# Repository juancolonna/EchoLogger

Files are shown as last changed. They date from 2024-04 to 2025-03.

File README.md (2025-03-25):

# EchoLogger Development Project

This repository contains the development project for EchoLogger, initiated and managed by the Institute of Computing (Instituto de Computação - IComp) at the Federal University of Amazonas (UFAM).

- **Project Leader and Coordinator:** Prof. PhD. Juan G. Colonna - [juancolonna@icomp.ufam.edu.br](mailto:juancolonna@icomp.ufam.edu.br)
- **Hardware Developer:** PhD. Márcio Alencar - [macalencar@gmail.com](mailto:macalencar@gmail.com)

## Contents

- **Hardware:** EasyEDA Project File and its variants as backups.
- **Software:** Micropython Firmware, basic libraries, and example codes.
- **Board Images:** Footprints, 2D/3D Images, and Logos.
- **Schematics:** Circuit schematics.
- **Documents:** General project documents, datasheets, and specifications.

## Project Overview

EchoLogger is a modularized low-cost development board project primarily aimed at monitoring environmental variables and recording sound. Its modular design facilitates the custom assembly of components to meet specific customer requirements. The device is tailored to streamline the non-industrialized production process by allowing the soldering of prefabricated components.

## Hardware Specifications

| TOP VIEW | BOTTOM VIEW|
|---|---|
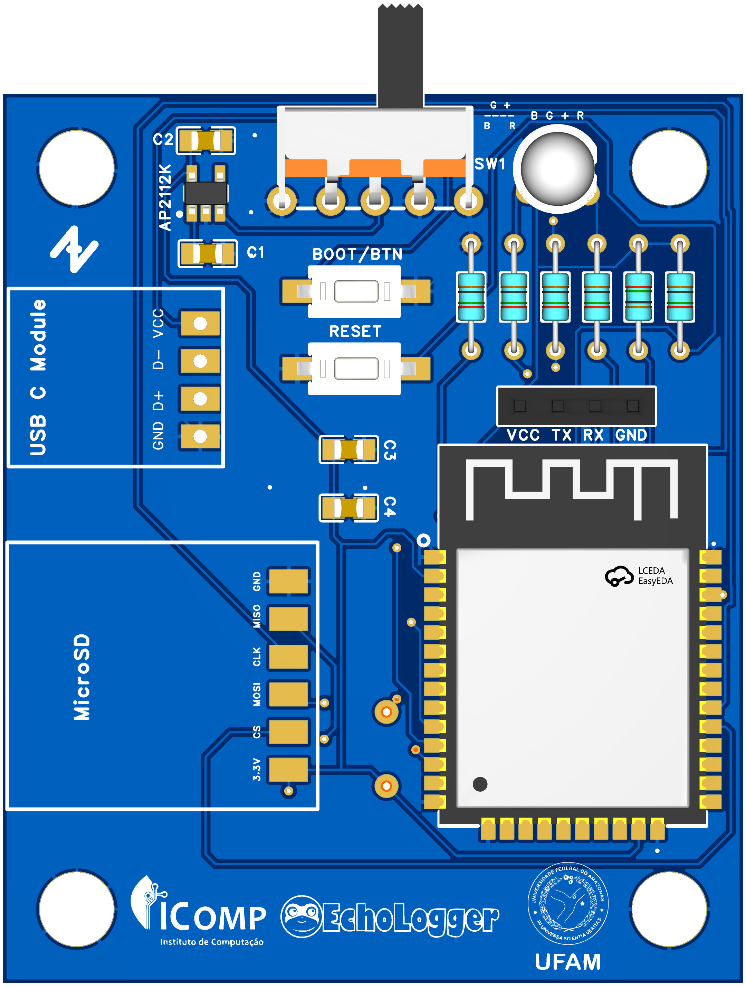
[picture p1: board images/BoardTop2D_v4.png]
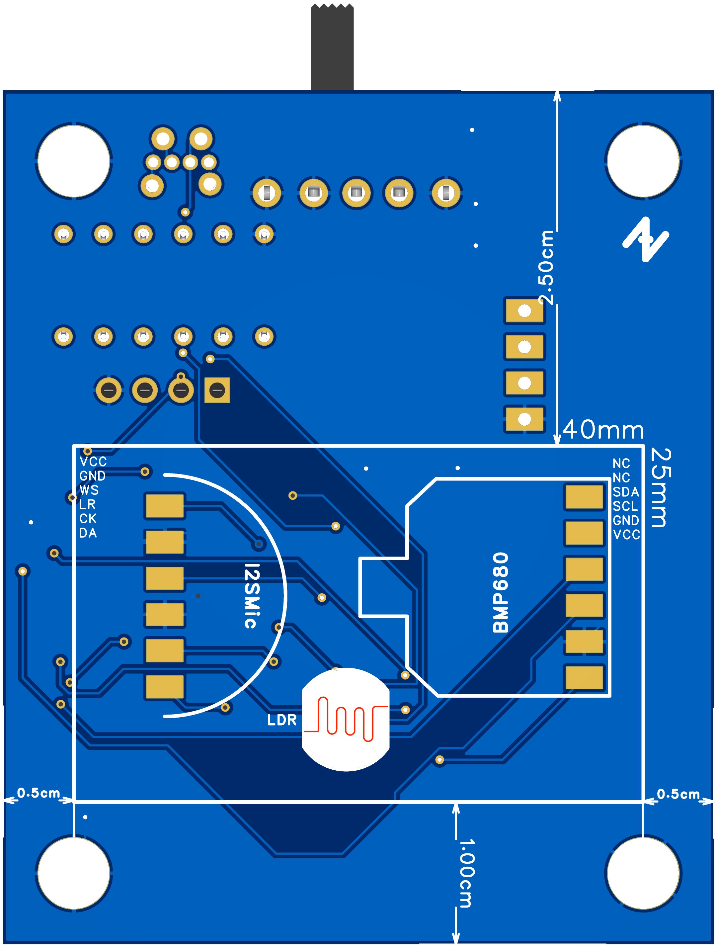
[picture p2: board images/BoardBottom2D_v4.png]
|||

- **Dimensions:** 600mm (length) x 500mm (width) x 130mm (height)
- **Microcontroller:** ESP32-WROOM-32S (BLE 4.0 & WiFi 802.11 b/g)
- **Sensors:**
  - I2C 4x1 Sensor BME680 (Temperature, Humidity, Air Pressure & Air Quality)
  - I2S Mic for noise recording
  - SPI MicroSD Card Module
  - LDR Sensor
- **Connectivity:** USB-C Module
- **Power Regulation:** Voltage Regulator AP2112K-3.3V
- **User Interface:** Reset Button, Boot Firmware Loader Button, RGB Led (Common Cathode), On/Off Switch
- **Additional Features:** UART Exposed Pins, 4x 5mm Holes, Isolated sensors on the bottom face for safety exposure

## Power Specifications

### Supply
- **AP2112K-3.3V:** 2.8V~6.5V @ 800mA (Regulated to 3.3v @ 600mA)

### Operation mode
- **Reading Sensors:** 50mA
- **Micro SD Writing:** 70mA
- **Deepsleep:** 15mA
- **Waking Up:** 100mA
- **Bluetooth:** 170mA (RX) ~ 200mA (TX)
- **WiFi:** 170mA (RX) ~ 260mA (TX)

### Consumption Estimation
- **Routine:** 1 min recording, 5 min sleeping
- **Cycle:** Sleep -> Wake Up -> Record -> Save Data -> Back to Sleep
- **Power Consumption Estimation:** 30mAh (3.3V - 0.15Wh)

### Deployment example!
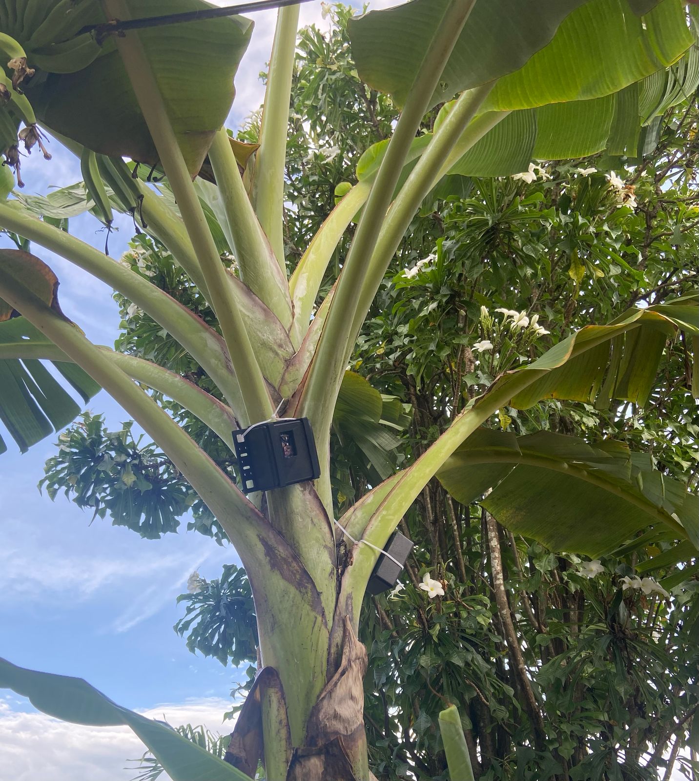
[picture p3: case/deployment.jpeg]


<!-- ## Additional Information -->

---
Feel free to reach out for any inquiries or collaborations!

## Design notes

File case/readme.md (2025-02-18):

STL files for case 3D printing

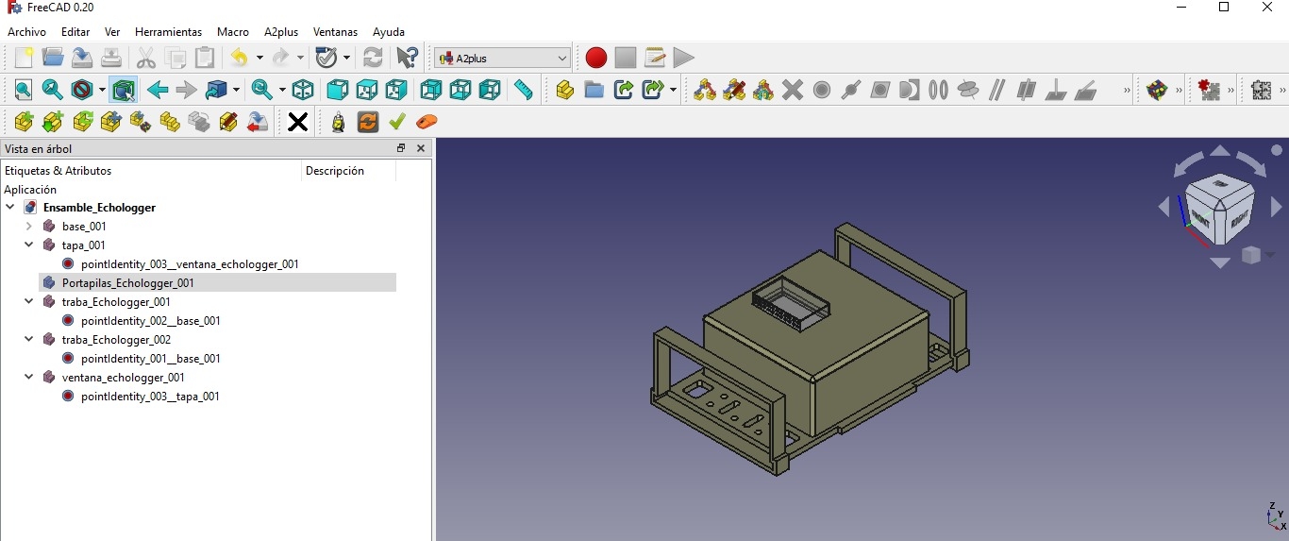
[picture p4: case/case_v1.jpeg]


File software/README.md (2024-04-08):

# Software Examples

This is folder contain the basic firmware and some python codes available for testing the board.

For that you may install the [esptool.py](https://github.com/espressif/esptool) for burning the firmware in the ESP, use the [mpy-cross](https://gitlab.com/alelec/mpy_cross) to 'compile' the `.py` codes and save some space, and then, send the `*.mpy` compiled files to the board using the [adafruit-ampy](https://github.com/scientifichackers/ampy) tool and a serial module.

Note: This tutorial used `Python 3.10.6`

### Install the requirements tools
```
pip install esptool
pip install adafruit-ampy
pip install mpy-cross
```

### Flashing the Micropython Firmware

1. Connect the power supply (5v) to the USB-C connector.
2. Connect the [Serial Module](https://www.smartkits.com.br/conversor-ftdi-ft232rl-com-chave-3-3v5v-vermelho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) (at 3.3v only) to the UART pins on the board (No need to connect VCC).
3. Identify the serial port of your serial module (Example using Windows - COM6).
4. Holding the `Boot/BTN` down, press & relase the `Reset` button.
5. Run the following command.

```
python -m esptool --chip esp32 --port COM6 erase_flash
```

After that, reset your device, execute the steps `4` and `5` again and run:

```
python -m esptool --chip esp32 --port COM6 --baud 460800 write_flash -z 0x1000 ./Micropython/ESP32_GENERIC-20231005-v1.21.0.bin
```

Reset the board again and it's done! Now your device has the Micropython firmware installed. 

We recommend to use the latest [Micropython for ESP32-WROOM](https://micropython.org/download/ESP32_GENERIC/) Version.

### Uploading the Demo Codes

This section describes how to send the basic library, available in `EX00_BasicLibs`, and use them in a demo application, available in `EX01_Bluetooth`. This demo tests all reseouces available in the board (mic, sensor, led, sdcard and bluetooth).

By using the [adafruit-ampy](https://github.com/scientifichackers/ampy) tool, you must save the basic library into the controller, for that, run the following commands:

```
ampy -b 115200 -p COM6 put ./EX00_BasicLibs/ble_advertising.py ble_advertising.py 
ampy -b 115200 -p COM6 put ./EX00_BasicLibs/bme680.py bme680.py 
ampy -b 115200 -p COM6 put ./EX00_BasicLibs/i2smic.py i2smic.py 
ampy -b 115200 -p COM6 put ./EX00_BasicLibs/RGBLib.py RGBLib.py 
```

Finally, save the main code `main.py` to run the device as a BLE Advertiser. For that you may install the `EchoLogger.apk` (Recommended) app in the `EX00_Extras` or use the `NRFConnect` from [PlayStore](https://play.google.com/store/apps/details?id=no.nordicsemi.android.mcp&pcampaignid=web_share) or [AppleStore](https://apps.apple.com/br/app/nrf-connect-for-mobile/id1054362403?platform=iphone).

```
ampy -b 115200 -p COM6 put ./EX01_Bluetooth/boot.py main.py 
```

Now, reset the device, run the app in yout smartphone, and connect to device called `EchoLogger`(NRFConnect) or click `Find and Connect` (EchoLogger.apk`)

Done!

### Connecting to the board using UART

Open you terminal monitor (suggested: [VSCode Serial Monitor by Microsoft](https://github.com/microsoft/vscode-serial-monitor_)) and connect to the board using the following configuration:

- Monitor Mode: Serial
- View Mode: Text
- Port: COM6 (*just following the previous example)
- Baud Rata: 115200
- Line ending: CRLF
- Data Bits: 8
- Stop bits: 1
- Parity: None
- DTR:  Checked
- RST: Checked

If everything went well, your device is ready to run your python commands.

This communication allows to interact with the Micropython terminal and run commands on demand, for example: 

```
print("Hello World")
```

Visit the [Micropython Documentation](https://docs.micropython.org/en/latest/) page for further informations on how to interacts with Micropython.

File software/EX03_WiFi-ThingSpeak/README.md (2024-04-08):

# Wifi + Thingspeak

This folder contains an example how to send data from your device to the [Thingspeak](https://thingspeak.com/) over wifi.

### Lib mrequests

This code uses a library called [mrequests)[https://github.com/SpotlightKid/mrequests] that implements the main REST methods (`GET, POST, PUT, UPDATE & DELETE`). To use it, run:

```
ampy -b 115200 -p COM6 put ./EX03_WIfi-Thingspeak/mrequests.py mrequests.py
```

Befor upload the `main.py` we need to update the `_APIKEY` value. This key must be generated in the section `API Keys > Write API Key` from [Thingspeak](https://thingspeak.com) dashboard. Make sure your Channel Settings contains 5 Fields at this order `Temperature, Humidity, Air Pressure, Air Quality` and `Light Intensity`:

```
#Thingspeak
_APIKEY = "YOUR_API_KEY_HERE"
_URL='https://api.thingspeak.com/update?api_key={}&field1={}&field2={}&field3={}&field4={}&field5={}'
```

You might have to include your Wifi's name (`_SSID``) and its password (`_PWD``)

```
#Wifi Credentials
_SSID="YOUR_SSID_HERE"
_PWD ="WIFI_PASSWORD_HERE"
```

Save the file and upload it to the board

```
ampy -b 115200 -p COM6 put ./EX03_WIfi-Thingspeak/main.py main.py
```

After that, reboot your device and access your [Thingspeak](https://thingspeak.com). 

Note: The API ignores demands an interval of 30s  between the last and a new request.

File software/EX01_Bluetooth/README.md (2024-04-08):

# BLE Demo

This folder contains the main code for a basic application using [Bluetooth Low Energy](https://docs.micropython.org/en/latest/library/bluetooth.html)

### BLE Service

This demos advertised the services as `Environmental Sensing Service` (`0x181A`) as defined [BLESpecifications](https://github.com/macalencar/PC20230001/tree/main/05_Docs/BLESpecifications)

This devices propagates the following characteristics :

- **Serial RX:** 6E400002-B5A3-F393-E0A9-E50E24DCCA9E   (Receive Data)
- **Serial TX:** 6E400002-B5A3-F393-E0A9-E50E24DCCA9E   (Transmit Data)
- **Air Pressure:** 0x2A6D
- **Temperature:** 0x2A6E
- **Humidity:** 0x2A6F
- **Air Quality:** 0x2AF9
- **Illuminance:** 0x2AFB
- **Device Time:** 0x2B90
- **Storege Free Space**: 0x2B04

This demo propagates the device name as `EchoLogger` and all values are published as a `Float 16`.

For further information go to [Bluetooth.org](https://www.bluetooth.com/bluetooth-resources/intro-to-bluetooth-low-energy/) or check the [Micropython BLE Documentation](https://docs.micropython.org/en/latest/library/bluetooth.html)

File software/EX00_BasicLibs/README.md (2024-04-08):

# Basic Libraries

This folder contains the basic libraries that help you to test the board funcionalities.

### RGBLib

Library that controlls the RGB led which is physically attached to the following ESP32 pins as follows:

- VCC: 3.3v
- RED: IO04
- GREEN: IO26
- BLUE: IO27

By using the `RGBLib` is is possible to instatiate an object that controlls the led as follow:

```
import RBGLib
LED = RBGLib.Controller(4,26,27)
LED.boot()

```

This library contains a set of pre-configured colors: `["black","red","green","blue","yellow","orange","pink","purple","cyan","white"]`. You may change the color by calling the method `LED.set('<COLOR>')`:

```
LED.set('blue')
LED.set('white')
LED.set('black')
LED.set('green')
```

You may also set manualy a led collor by define the RGB values using the method `LED.man(r,g,b)`. Each `r,g,b` values may assume any value from `0` to `1023`:

```
LED.man(100,200,300)
```

### BME680

This library controls the sensor [BME650](https://datasheet.lcsc.com/lcsc/1811141211_Bosch-Sensortec-BME680_C125972.pdf) by using a [SoftI2C](https://docs.micropython.org/en/latest/library/machine.I2C.html) classe which is connected to the board as the following:

- VCC: 3.3v
- GND: GND
- SDA: IO22
- SCL: IO21

You may create an object to controll the BME680 module by indicating a [SoftI2C](https://docs.micropython.org/en/latest/library/machine.I2C.html) object as following:

```
from machine import SoftI2C, Pin
import bme680

i2c = SoftI2C(scl=Pin(22), sda=Pin(21))
bme = BME680_I2C(i2c=i2c)

print("Temperature: {} ºC\n".format(bme.temperature))
print("Humidity: {} %".format(bme.humidity))
print("Air Pressure: {} HPa".format(bme.pressure))
print("Air Quality: {} IAQ".format(bme.gas))

```

### I2S Mic

This module controlls the [I2S](https://docs.micropython.org/en/latest/library/machine.I2S.html#machine.I2S) Microphone, it requires a [MicrSD Card](https://docs.micropython.org/en/latest/library/machine.SDCard.html) to store the recorded audio.

The SDCard module is connected to `ESP32`` as follows:

- VCC: 3.3v
- GND: GND
- CS: IO05
- MOSI: IO23
- CLK: IO18
- MISO: IO19

The I2SMic is connectes as follows:

- GND: GND
- VCC: 3.3v
- WS: IO25
- L/R: GND (it could be VCC)
- CK: IO32
- DA: IO33

Make sure that your sd card if formated as `FAT32` and inserted in the module's slot. After that, execute the following commands:

```
from machine import SDCard
import i2smic
import time

i2c = SDCard(slot=2)
os.mount(_SD, "/sd") 
MIC = i2smic.Controller()

MIC.record('/sd/output_file.wav')
time.sleep(10)
MIC.stop()

```

The `*.WAV` file are stored in the micro SD card.

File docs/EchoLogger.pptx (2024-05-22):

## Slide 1

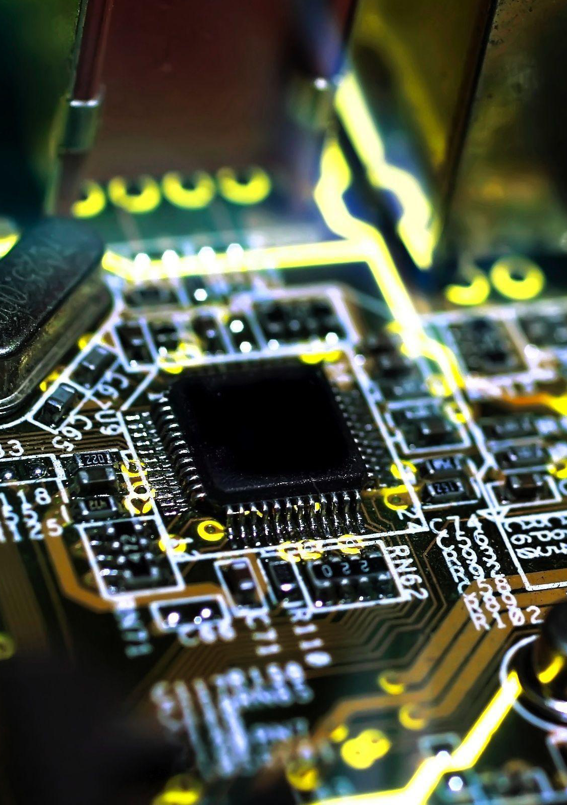
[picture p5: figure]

Reuniões Semanais #6
PC2023:0001:V3

ATA

Alencar Tecnologia da Amazonia.
CNPJ: 45.845.459/0001-24

## Agenda

- Hardware Overview;
- Components Description;
- Power Consumption;
- Data Sampling;
- Application;

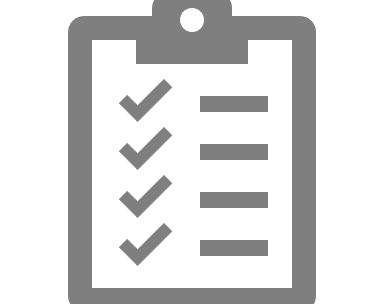
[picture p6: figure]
Área de Transferência Marcada com preenchimento sólido

Alencar Tecnologia da Amazonia
CNPJ: 45.845.459/0001-24

ATA

## Hardware Overview

- Custom Board
- Controller:
  - ESP32 WROOM (BLE v4.0 & Wifi 802.11 b/g)
  - Embedded RTC
  - Firmware Micropython 1.20
- Storage:
  - micro SD Card Slot
- Sensors:
  - 4x1 I2C Temperature, Humidity, Air Pressure and Air Quality
  - Mic I2S
  - LDR 5mm (ADC)

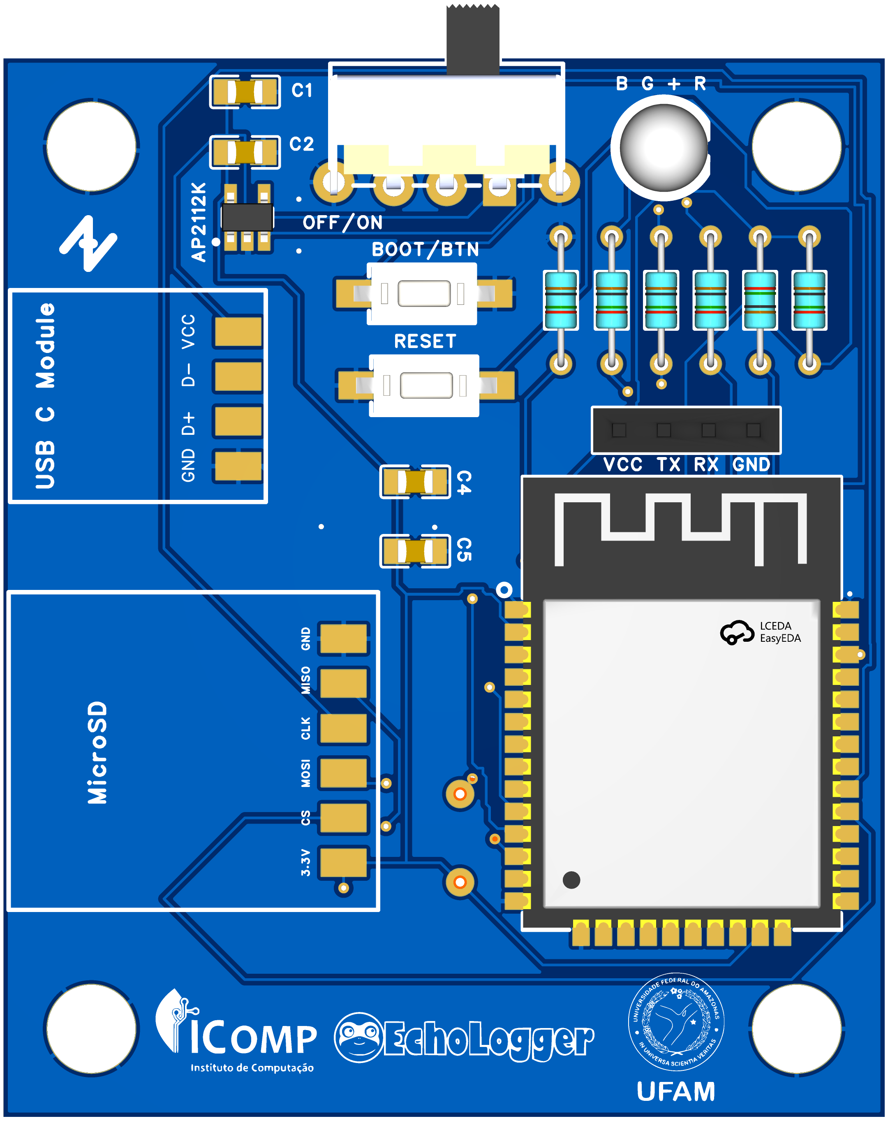
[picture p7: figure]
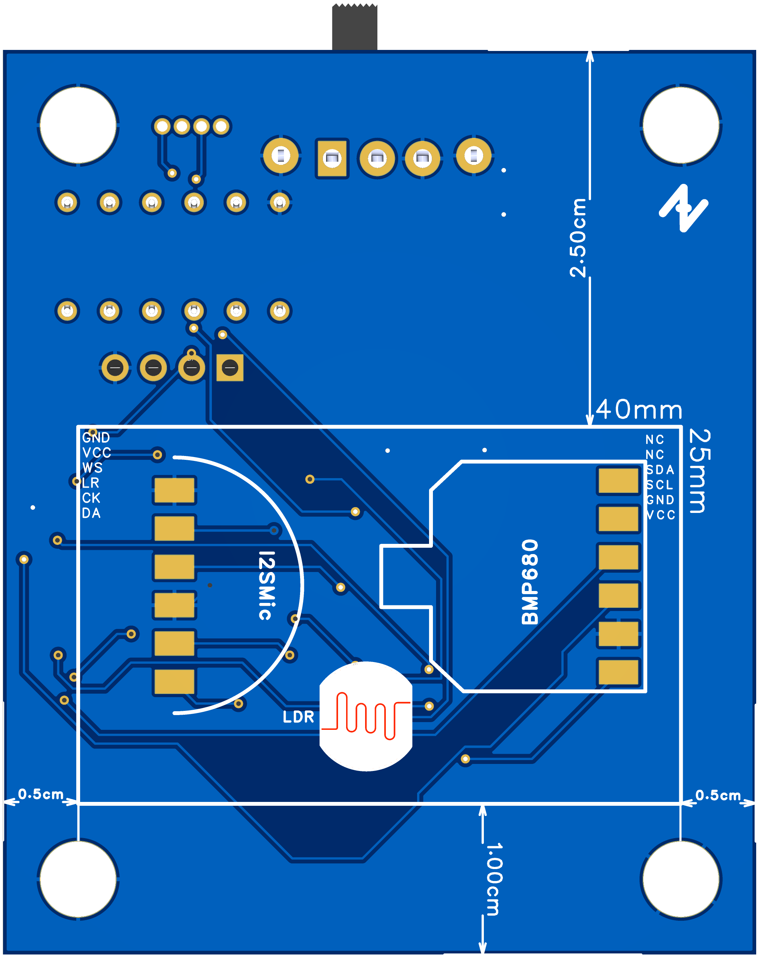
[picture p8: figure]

Alencar Tecnologia da Amazonia
CNPJ: 45.845.459/0001-24

ATA

## Hardware Overview

- Custom Board
- Dimensions:
  - 60mm x 50mm x 20mm
- Other characteristics:
  - 4x Holes for board supporting: 5mm
  - 1x Led RGB THP
  - 2x Pushbuttons: Reset / Boot (firmware writing or regular button)
  - USB Breakout Pads
  - Voltage Regulator AP2112K-TGR-3.3v
  - Exposed UART vias

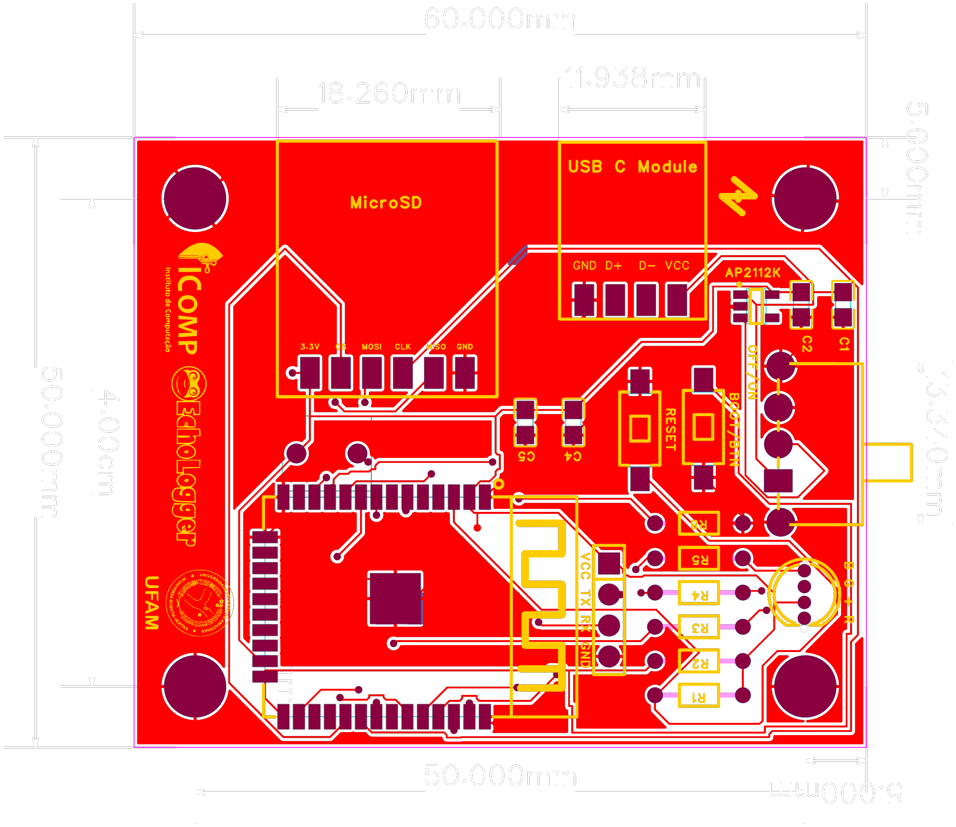
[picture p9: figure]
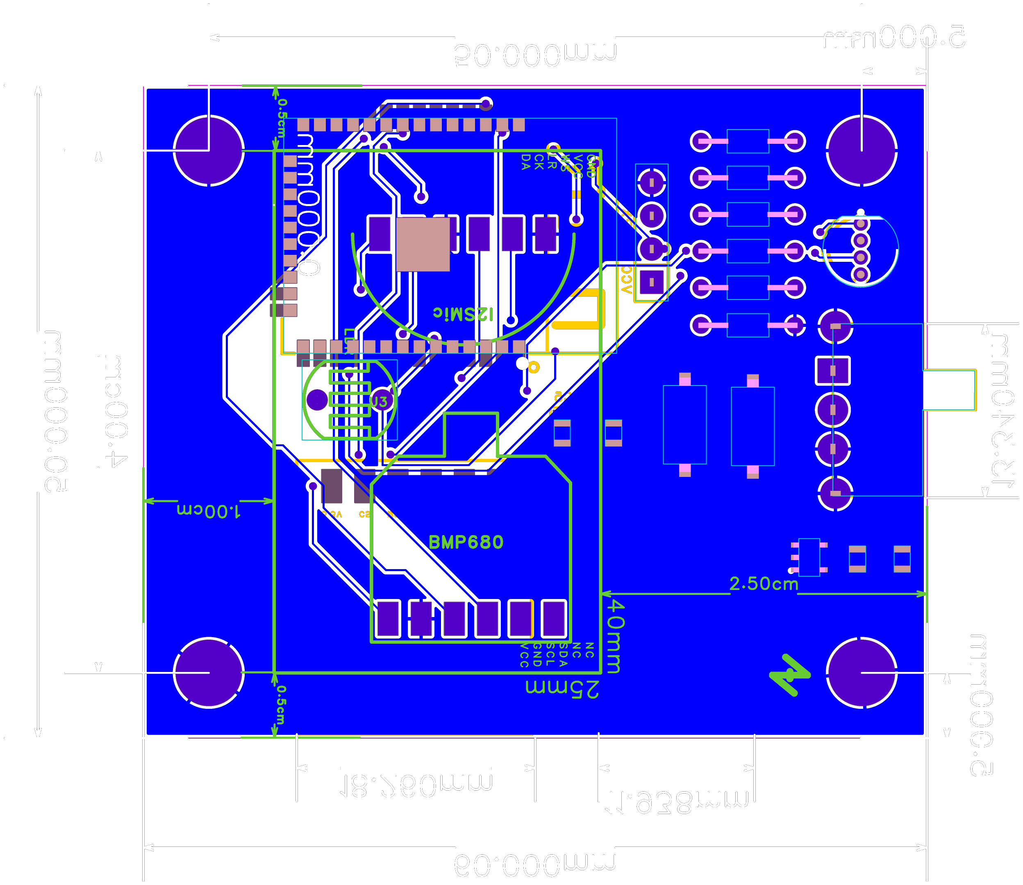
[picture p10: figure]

Alencar Tecnologia da Amazonia
CNPJ: 45.845.459/0001-24

ATA

## Components Descriptions

Component | Value
USB Power Supply (Module) | ~ 0.40
Voltage Regulator (AP2112) | ~ 0.10
LDR (Photoresistor) 5mm | ~ 0.01
Led RGB THP 5mm | ~ 0.02
MicroSD Module | ~ 0.25
I2S Mic | ~ 1.80
BME680 4x1 Sensor | ~ 3.70
ESP32-WROOM-32 | ~ 3.50
PCB | ~ 5.00
PowerBank (50A) | ~ 20.00
Waterproof Box – IP67 – 20x12x7.5cm | ~ 10.00
ESTIMATED COST | ~ 44,78

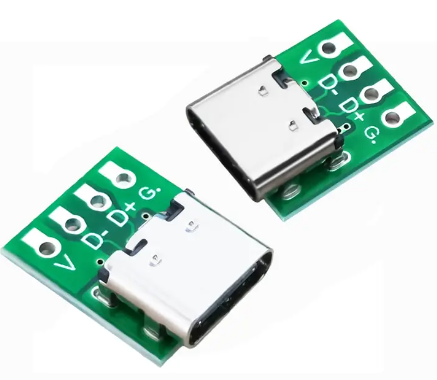
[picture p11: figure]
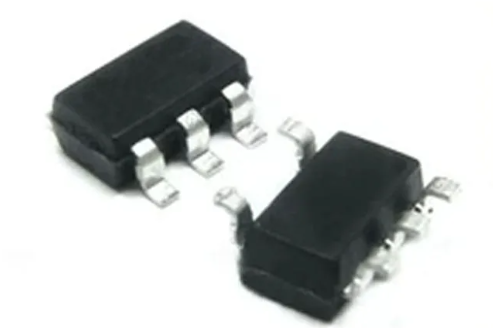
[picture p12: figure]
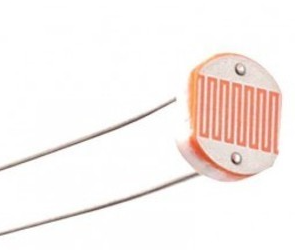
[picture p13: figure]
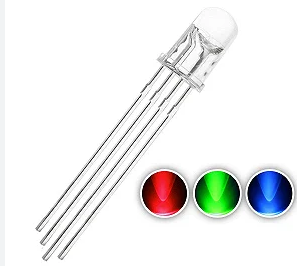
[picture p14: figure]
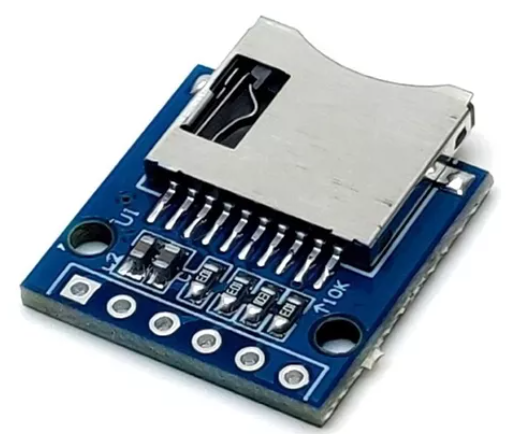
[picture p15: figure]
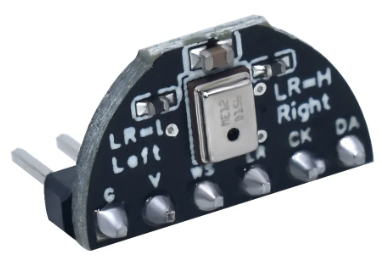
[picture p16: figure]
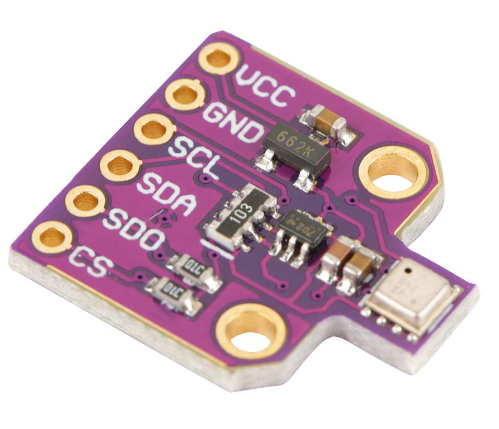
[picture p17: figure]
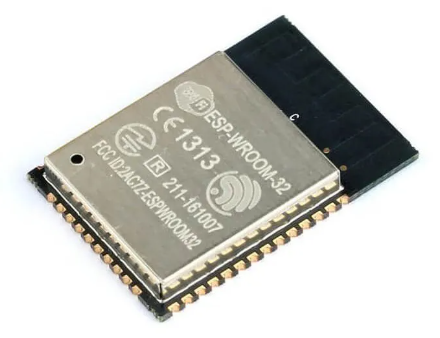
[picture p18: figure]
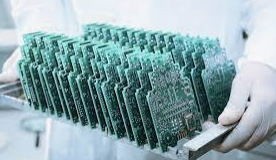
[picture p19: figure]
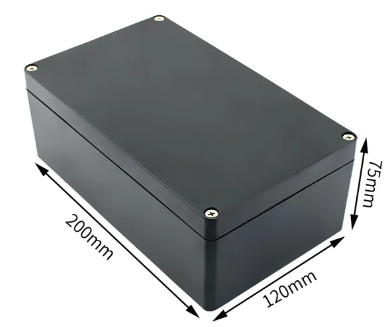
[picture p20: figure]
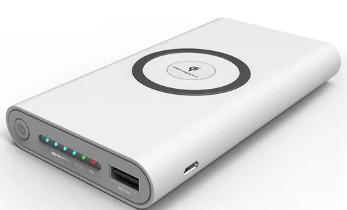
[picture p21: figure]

Alencar Tecnologia da Amazonia
CNPJ: 45.845.459/0001-24

ATA

## Power Consumption

- Power Supply:
- APK2112: 2.8V ~ 6.5V @ 800A - 3.3V @ 600mA
- Operation mode:
- Reading Sensors: 50mA
- SD Writing: 70mA
- Deepsleep: 15mA
- Waking up: 100mA
- BLE: 170mA (TX) ~ 200mA (RX)

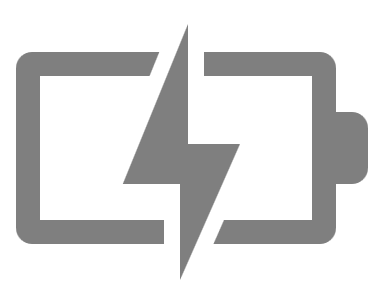
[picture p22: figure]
Carregamento da bateria com preenchimento sólido

Alencar Tecnologia da Amazonia
CNPJ: 45.845.459/0001-24

ATA

## Power Consumption

- Consumption Estimation:
- Routine: 1 min recording, 5 min sleeping;
- Cycle: Sleep (5min), Wakeup (2s), Record (1min), Writing (2s)
- Repetat the cycle for 1 hour (~ 10 cycles / hour)

Current (mA/h) | Activity (duration/hour)
12,5 | Sleeping (~50 min/hour)
0,555556 | Waking Up (~20sec/hour)
8,333333 | Recording (~10min/hour)
0,388889 | Writing (~20sec/hour)
21,77778 | Routine Consumption (mAh)
Estimation 30mAh (3.3V - 0.15 Wh)

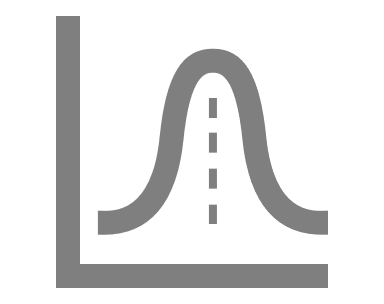
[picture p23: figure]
Distribuição normal com preenchimento sólido

Alencar Tecnologia da Amazonia
CNPJ: 45.845.459/0001-24

ATA

## Data sampling

Alencar Tecnologia da Amazonia
CNPJ: 45.845.459/0001-24

ATA

## Data sampling

- Audio Samples:
- File name: record_N.wav
- Format: WAV
- Storage Consumption: 2.55MB/min
- Audio splited in 1 min chunks

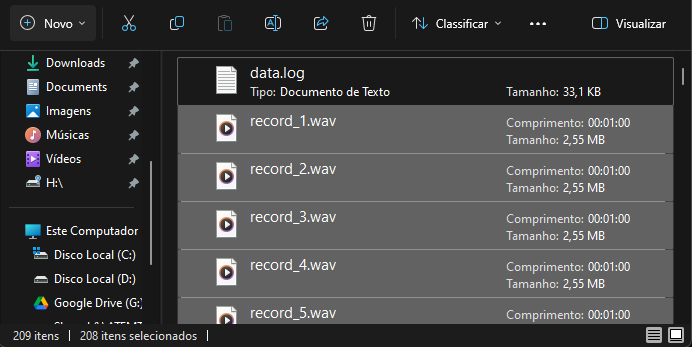
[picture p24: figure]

Alencar Tecnologia da Amazonia
CNPJ: 45.845.459/0001-24

ATA

## Application

- Bluetooth Low Energy Configuration
  - Real time data (Sensor Readings)
  - Date Time / GPS Coordinates Sync
  - Scheduling Management
- Activity Scheduling
  - Days of Week
  - Start Time
  - Start Date
  - Recording Interval: 0 (disabled) ~ 24h
  - Multiple Scheduling

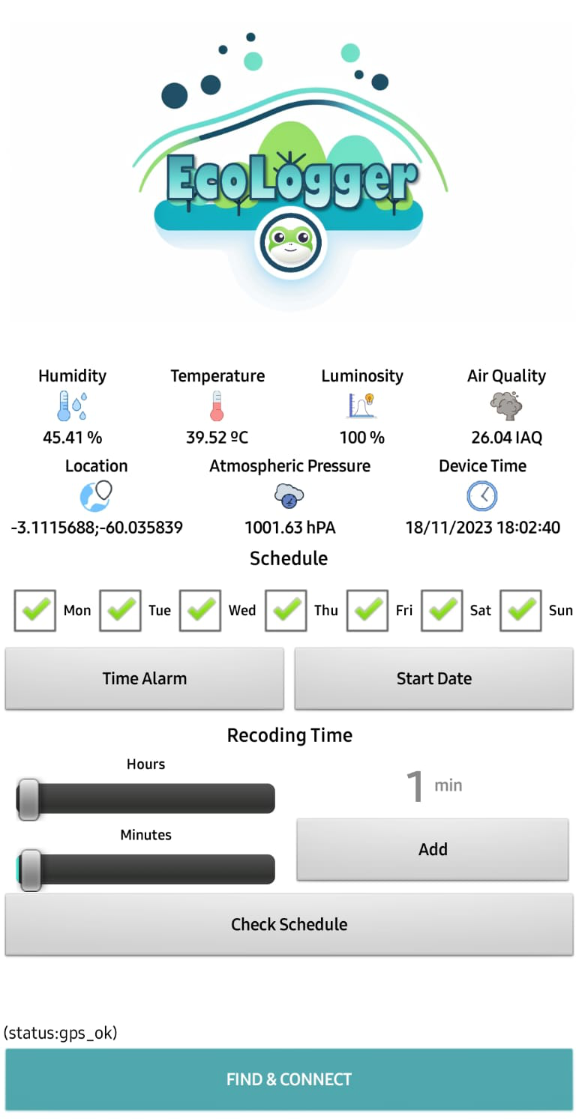
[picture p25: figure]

Alencar Tecnologia da Amazonia
CNPJ: 45.845.459/0001-24

ATA

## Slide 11

Obrigado!
PC2023:0001:V3

ATA

Alencar Tecnologia da Amazonia.
CNPJ: 45.845.459/0001-24

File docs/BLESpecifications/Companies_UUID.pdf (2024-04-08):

Embedded Planet | Agora BLE Reference Specification | BLE GATT Profile Specification
Date: 17-July-2019 | Document Version: 0.4 | Prepared by: G. Beckstein

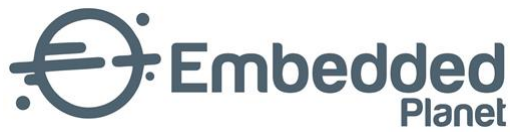
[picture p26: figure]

Embedded Planet Confidential – Do not copy or reproduce without expressed written consent of Embedded Planet, Inc.

### Document Revision History

Date | Description | Author | Version
18-June-2019 | Initial version. | G. Beckstein | 0.1
24-June-2019 | Revised from internal comments | G. Beckstein | 0.2
1-July-2019 | Modified services/characteristics to more closely mirror LWM2M | G. Beckstein | 0.3
17-July-2019 | Changed ICM20602 and LSM9DS1 data struct members from int16 to float | G. Beckstein | 0.4
23-October-2019 | Changed temperature Celsius (0x2A1F) to temperature (0x2A6E) | G. Beckstein | 0.5
23-October-2019 | Added Firmware Revision String characteristic (0x2A26) to Device Information Service (0x180A) | G. Beckstein | 0.5

### Sign-Off

Signature | Date
Marketing | ☐
Operations | ☐
Purchasing | ☐
Engineering | ☐

### Distribution

CEO | ☐
Admin | ☐
Engineering | ☐
Marketing | ☐
Operations | ☐
Purchasing | ☐

Embedded Planet, Inc.
4760 Richmond Road, Suite 400 Warrensville Heights, OH 44128 216-245-4180 p
216-292-0561 f

### 1.0 Purpose

This BLE Protocol Specification (BPS) document describes the Bluetooth Low Energy (BLE) profile of the Agora Product. This specification is based on standards published by the Bluetooth SIG and the array of sensors built into the Agora hardware.

For detailed hardware functionality, please refer to the Hardware Functional Specification (DES0263).

### 2.0 Document Conventions

General definition of requirement terms:
- SHALL - This word means that the definition is an absolute requirement of the specification.
- SHALL NOT - This phrase means that the definition is an absolute prohibition of the specification.
- SHOULD- This word means that there may exist valid reasons in particular circumstances to ignore a particular item, but the full implications must be understood and carefully weighed before choosing a different course.
- SHOULD NOT - This phrase means that there may exist valid reasons in particular circumstances when the particular behavior is acceptable or even useful, but the full implications should be understood, and the case carefully weighed before implementing any behavior described with this label.
- MAY - This word mean that an item is truly discretionary.

### 3.0 References

Description | Document | Rev / Date | Owner

### 4.0 Acronyms and Abbreviations

Term | Description
EPI | Embedded Planet Inc.
BSP | Board Support Package
SIG | Bluetooth Special Interest Group
BLE | Bluetooth Low Energy (aka Bluetooth Smart)
GAP | Generic Access Profile (part of BLE specification)
GATT | Generic Attribute Profile (part of BLE specification)
UUID | Universally Unique Identification Number
IAQ | Indoor Air Quality
IMU | Inertial Measurement Unit
ALS | Ambient Light Sensor

### 5.0 Definitions

Term | Description
BLE Characteristic | A BLE endpoint encapsulating a single data point. Characteristics typically expose up to 20 bytes at a time of data in a single transaction.
BLE Service | A service defines a set of mandatory and optional characteristics that exist under one UUID.
BLE Profile | A profile defines a set of mandatory and optional services that exist on a device.
BLE Peripheral | A connectable device that periodically broadcasts advertisements of its presence with a small payload describing itself. A BLE central can connect to this device.
BLE Central | A device that scans for advertising peripherals and issues connection packets. (e.g.: a BLE-enabled smartphone)

### 6.0 Description of Pairing Procedure

### 6.1 Advertising – No Paired Centrals

When first powered on, the Agora device shall advertise as a BLE peripheral. It shall advertise in undirected connectable mode. In this mode, the peripheral allows persistent connections from central devices and periodically broadcasts general advertisements to all nearby central devices.
The advertisement payload shall contain identifiable information that will distinguish the Agora BLE peripheral from other nearby BLE peripherals. This identifiable information shall consist of at least:
1.) The 128-bit Agora BLE Service UUID as described in section 7. This may be used by the central device application to filter unrelated BLE peripherals.
2.) The last two bytes of the device’s Bluetooth MAC address which may be used to uniquely identify a single Agora device when several are advertising within range.

### 6.2 Connection Procedure and Pairing

When a connection is initiated by a central device, for example a compatible application on a nearby gateway, the Agora device shall request the connection security to be upgraded. As the central, the gateway application is responsible for carrying out this request and may choose to initiate the BLE bonding procedure.
During the BLE bonding procedure, encryption keys are securely exchanged between the central and peripheral. Both the central and peripheral store the keys and unique identifiers in non-volatile memory.

### 6.3 Advertising – Paired Centrals

When an Agora device powers on and has a previously paired central stored in memory, it shall advertise as a BLE peripheral in directed connectable mode. In this mode, advertisements shall be targeted towards the last central the Agora device was connected to. This enables a connection to be established more quickly with a previously paired central.
If the intended central fails to reconnect within several seconds, the Agora device shall then revert to advertise in undirected connectable mode as described in section 6.1.

### 7.0 Agora BLE Profile Description

Custom BLE service UUIDs from a single manufacturer typically derive from the same 128-bit base UUID. The Embedded Planet base UUID is shown in the table below:

Base UUID

0000xxxx-8dd4-4087-a16a-04a7c8e01734
The ‘x’ characters indicate the position of the alias of BLE properties (service and characteristic UUIDs).

Services and characteristics standardized by the Bluetooth SIG cover common BLE application requirements. Standardized services and characteristics are typically identified by a shorter, 16-bit UUID. This 16-bit UUID can be expanded using the Bluetooth SIG’s 128-bit base UUID. However, for brevity, this document will only refer to the short-form, 16-bit UUID of standard services and characteristics.

The Agora product encompasses several product variants with optional components left unpopulated in some cases. As a result, some services described below may not be present in the profile of a specific Agora unit. If a service is not present it means that part is not populated on the board. The connected application should be aware of this and respond to missing services appropriately.

### 7.1 Services

The Agora BLE profile shall consist of several standardized and custom services. Bluetooth SIG standardized services included in the profile are listed in the table below:

Standard Services

UUID | Name | Relevant Specification
0x1800 | Generic Access Service | org.bluetooth.service.generic_access (https://www.bluetooth.com/wp-content/uploads/Sitecore-Media-Library/Gatt/Xml/Services/org.bluetooth.service.generic_access.xml)
0x180A | Device Information Service | org.bluetooth.service.device_information (https://www.bluetooth.com/wp-content/uploads/Sitecore-Media-Library/Gatt/Xml/Services/org.bluetooth.service.device_information.xml)

Each on-board sensor or actuator is associated with a corresponding custom service. Custom services are described in the table below:

Custom Services

Alias | Name | Full UUID
0x0001 | BME680 Service | 00000001-8dd4-4087-a16a-04a7c8e01734
0x0002 | Si7021 Service | 00000002-8dd4-4087-a16a-04a7c8e01734
0x0003 | ICM-20602 6-Axis IMU Service | 00000003-8dd4-4087-a16a-04a7c8e01734
0x0004 | LSM9DS1 9-Axis IMU Service | 00000004-8dd4-4087-a16a-04a7c8e01734
0x0005 | MAX44009 Ambient Light Service | 00000005-8dd4-4087-a16a-04a7c8e01734
0x0006 | VL53L0X Time-of-Flight Service | 00000006-8dd4-4087-a16a-04a7c8e01734
0x0008 | LED Service | 00000008-8dd4-4087-a16a-04a7c8e01734
0x0009 | Battery Voltage Service | 00000009-8dd4-4087-a16a-04a7c8e01734

The characteristics of each of these services are described in the following sections.

Non-standardized characteristics will be associated with a specified data format as outlined by the Bluetooth SIG here. (https://www.bluetooth.com/specifications/assigned-numbers/format-types/)
The units of the data will also be described. This information shall be available “on-air” by accessing the specific
characteristic’s Characteristic Presentation Format descriptor. (https://www.bluetooth.com/wp-content/uploads/Sitecore-Media-Library/Gatt/Xml/Descriptors/org.bluetooth.descriptor.gatt.characteristic_presentation_format.xml)

### 7.1.1 Generic Access Service

The Generic Access service contains generic information about the device. All available Characteristics are read only. The table below summarizes implemented characteristics of this service:

Standard Characteristics

UUID | Name | Permissions | Relevant Specification
0x2A00 | Device Name | Read | org.bluetooth.characteristic.gap.device_name (https://www.bluetooth.com/wp-content/uploads/Sitecore-Media-Library/Gatt/Xml/Characteristics/org.bluetooth.characteristic.gap.device_name.xml)
0x2A01 | Appearance | Read | org.bluetooth.characteristic.gap.appearance (https://www.bluetooth.com/wp-content/uploads/Sitecore-Media-Library/Gatt/Xml/Characteristics/org.bluetooth.characteristic.gap.appearance.xml)

### 7.1.2 Device Information Service

The Device Information Service exposes manufacturer and/or vendor information about a device. The table below summarizes implemented characteristics of this service:

Standard Characteristics

UUID | Name | Permissions | Relevant Specification
0x2A29 | Manufacturer Name | Read | org.bluetooh.characteristic.manufacturer_name_string (https://www.bluetooth.com/wp-content/uploads/Sitecore-Media-Library/Gatt/Xml/Characteristics/org.bluetooth.characteristic.manufacturer_name_string.xml)
0x2A24 | Model Number String | Read | org.bluetooth.characteristic.model_number_string (https://www.bluetooth.com/wp-content/uploads/Sitecore-Media-Library/Gatt/Xml/Characteristics/org.bluetooth.characteristic.model_number_string.xml)
0x2A25 | Serial Number String | Read | org.bluetooth.characteristic.serial_number_string (https://www.bluetooth.com/wp-content/uploads/Sitecore-Media-Library/Gatt/Xml/Characteristics/org.bluetooth.characteristic.serial_number_string.xml)
0x2A26 | Firmware Revision String | Read | org.bluetooth.characteristic.firmware_revision_string (https://www.bluetooth.com/wp-content/uploads/Sitecore-Media-Library/Gatt/Xml/Characteristics/org.bluetooth.characteristic.firmware_revision_string.xml)
0x2A27 | Hardware Revision String | Read | org.bluetooth.characteristic.hardware_revision_string (https://www.bluetooth.com/wp-content/uploads/Sitecore-Media-Library/Gatt/Xml/Characteristics/org.bluetooth.characteristic.hardware_revision_string.xml)
0x2A28 | Software Revision String | Read | org.bluetooth.characteristic.software_revision_string (https://www.bluetooth.com/wp-content/uploads/Sitecore-Media-Library/Gatt/Xml/Characteristics/org.bluetooth.characteristic.software_revision_string.xml)

### 7.1.3 BME680 Service

The BME680 is a highly integrated environmental sensor capable of transducing ambient temperature, pressure, relative humidity, and relative VOC concentration. By combining these readings, the application can give a measure of indoor air quality (IAQ). The BME680 service characteristics are listed in the table below:

Standard Characteristics

UUID | Name | Permissions | Relevant Specification
0x2A6E | Temperature | Read, Notify, Indicate | org.bluetooth.characteristic.temperature (https://www.bluetooth.com/wp-content/uploads/Sitecore-Media-Library/Gatt/Xml/Characteristics/org.bluetooth.characteristic.temperature.xml)
0x2A6F | Humidity | Read, Notify, Indicate | org.bluetooth.c haracteristic.humidity (https://www.bluetooth.com/wp-content/uploads/Sitecore-Media-Library/Gatt/Xml/Characteristics/org.bluetooth.characteristic.humidity.xml)
0x2A6D | Pressure | Read, Notify, Indicate | org.bluetooth.characteristic.pressure (https://www.bluetooth.com/wp-content/uploads/Sitecore-Media-Library/Gatt/Xml/Characteristics/org.bluetooth.characteristic.pressure.xml)

Custom Characteristics

Alias | Name | Units (ID) | Data format (ID) | Permissions | Full UUID

0x1001 | Estimated CO2 Concentration | Concentration in ppm (0x27C4) | float32 (0x14) | Read, Notify, Indicate | 00001001-8dd4-4087-a16a-04a7c8e01734
0x2001 | Estimated b-VOC Equivalents | Concentration in ppm (0x27C4) | float32 (0x14) | Read, Notify, Indicate | 00002001-8dd4-4087-a16a-04a7c8e01734
0x3001 | Indoor Air Quality Score (0-500) | Unitless (0x2700) | uint16 (0x06) | Read, Notify, Indicate | 00003001-8dd4-4087-a16a-04a7c8e01734
0x4001 | Indoor Air Quality Accuracy Score (0-3) | Unitless (0x2700) | uint8 (0x04) | Read, Notify, Indicate | 00004001-8dd4-4087-a16a-04a7c8e01734
0x5001 | Gas Resistance | Ohm (0x272A) | uint32 (0x08) | Read, Notify, Indicate | 00005001-8dd4-4087-a16a-04a7c8e01734

The Indoor Air Quality Score corresponds to the descriptions in the following table:

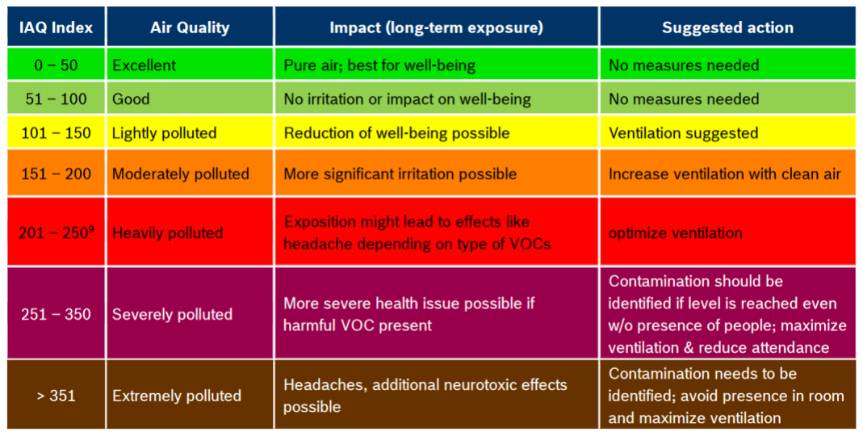
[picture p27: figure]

### 7.1.4 Si7021 Service

The Si7021 combines a relative humidity and temperature sensor. It offers a redundant temperature and humidity reading when populated with the BME680 (described in section 7.1.1), or a simpler solution for temperature and humidity sensing if used alone. The Si7021 service exposes a subset of the characteristics included in the BME680 service.

Standard Characteristics

UUID | Name | Permissions | Relevant Specification
0x2A6E | Temperature | Read, Notify, Indicate | org.bluetooth.characteristic.temperature (https://www.bluetooth.com/wp-content/uploads/Sitecore-Media-Library/Gatt/Xml/Characteristics/org.bluetooth.characteristic.temperature.xml)
0x2A6F | Humidity | Read, Notify, Indicate | org.bluetooth.characteristic.humidity (https://www.bluetooth.com/wp-content/uploads/Sitecore-Media-Library/Gatt/Xml/Characteristics/org.bluetooth.characteristic.humidity.xml)

### 7.1.5 ICM-20602 6-Axis IMU Service

The ICM-20602 is a 6-axis inertial measurement unit providing 3-axis accelerometer and 3-axis gyroscope readings.

Custom Characteristics

Alias | Name | Units (ID) | Data format (ID) | Permissions | Full UUID
0x1003 | Accelerometer XYZ | Acceleration (0x2713) | struct (0x1B) (see 7.1.5.1) | Read | 00001003-8dd4-4087-a16a-04a7c8e01734
0x2003 | Gyroscope XYZ | Angular Veloctity (0x2743) | struct (0x1B) | Read | 00002003-8dd4-4087-a16a-04a7c8e01734

### 7.1.5.1 Accelerometer/Gyroscope XYZ Structure

The accelerometer and gyroscope XYZ characteristics shall contain a struct that encapsulates three 32-bit floating-point values for each axis, X, Y, and Z, respectively. They shall be packed into a 12-byte packet.

### 7.1.6 LSM9DS1 9-Axis IMU Service

The LSM9DS1 is a 9-axis IMU and offers an additional/alternate source of accelerometer and gyroscope data as well as 3-axis magnetometer data. As such, the LSM9DS1 service contains the same characteristics as the ICM-20602 Service (described in section 7.1.3) and additional characteristics related to the magnetometer functionality.

Custom Characteristics

Alias | Name | Units (ID) | Data format (ID) | Permissions | Full UUID
0x1003 | Accelerometer XYZ | Acceleration (0x2713) | struct (0x1B) (see 7.1.5.1) | Read | 00001003-8dd4-4087-a16a-04a7c8e01734
0x2003 | Gyroscope XYZ | Angular Velocity (radians/sec) (0x2743) | struct (0x1B) | Read | 00002003-8dd4-4087-a16a-04a7c8e01734
0x3004 | Magnetometer XYZ | Magnetic Flux Density (teslas) (0x272D) | struct (0x1B) | Read | 00003004-8dd4-4087-a16a-04a7c8e01734

### 7.1.7 MAX44009 Ambient Light Sensor Service

The MAX44009 incorporates two ambient light sensors – each having a different response to various wavelengths of light. One of the sensors rejects infrared light to better represent the ambient light conditions as seen by the human eye. The other sensor accepts more infrared and less visible light. The two readings are combined to provide a more “realistic” reading under a variety of lighting conditions.

The MAX44009 ALS Service has the following characteristics:
Custom Characteristics
Alias | Name | Units (ID) | Data format (ID) | Permissions | Full UUID
0x1005 | Ambient Light | Lux (0x2731) | float32 (0x14) | Read, Notify, Indicate | 00001005-8dd4-4087-a16a-04a7c8e01734

### 7.1.8 VL53L0X Time-of-Flight Service

The VL53L0X time-of-flight sensor can measure the distance to nearby objects up to 2 meters away. An example application of this data is the possibility of tamper detection if the device is moved or opened by an unauthorized person.

The VL53L0X Time-of-Flight Service has the following characteristics:

Custom Characteristics

Alias | Name | Units (ID) | Data format (ID) | Permissions | Full UUID
0x1006 | Distance | Meter (0x2701) (in increments of 0.001) | uint16 (0x06) | Read, Notify, Indicate | 00001006-8dd4-4087-a16a-04a7c8e01734

### 7.1.9 LED Service

The LED service exposes read/write control to the state of the on-board LED. This service functions identically to the service implemented in the Mbed-OS BLE LED example application found here. (https://github.com/ARMmbed/mbed-os-example-ble/tree/master/BLE_LED) A value of true is associated with the illuminated LED state.

Custom Characteristics

Alias | Name | Units (ID) | Data format (ID) | Permissions | Full UUID
0x1008 | LED State | Unitless (0x2700) | boolean (0x01) | Read, Write | 00001008-8dd4-4087-a16a-04a7c8e01734

### 7.1.10 Battery Voltage Service

The Battery Voltage Service exposes a raw reading of the current on-board battery voltage. This can be used to estimate remaining battery life.

Custom Characteristics

Alias | Name | Units (ID) | Data format (ID) | Permissions | Full UUID
0x1009 | Battery Voltage | Volts (0x2728) | float32 (0x14) | Read, Notify, Indicate | 00001009-8dd4-4087-a16a-04a7c8e01734

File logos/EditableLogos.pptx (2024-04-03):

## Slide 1

EchoLogger


EchoLogger

00EchoLogger

EchoLogger

00EchoLogger

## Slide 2


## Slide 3


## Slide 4


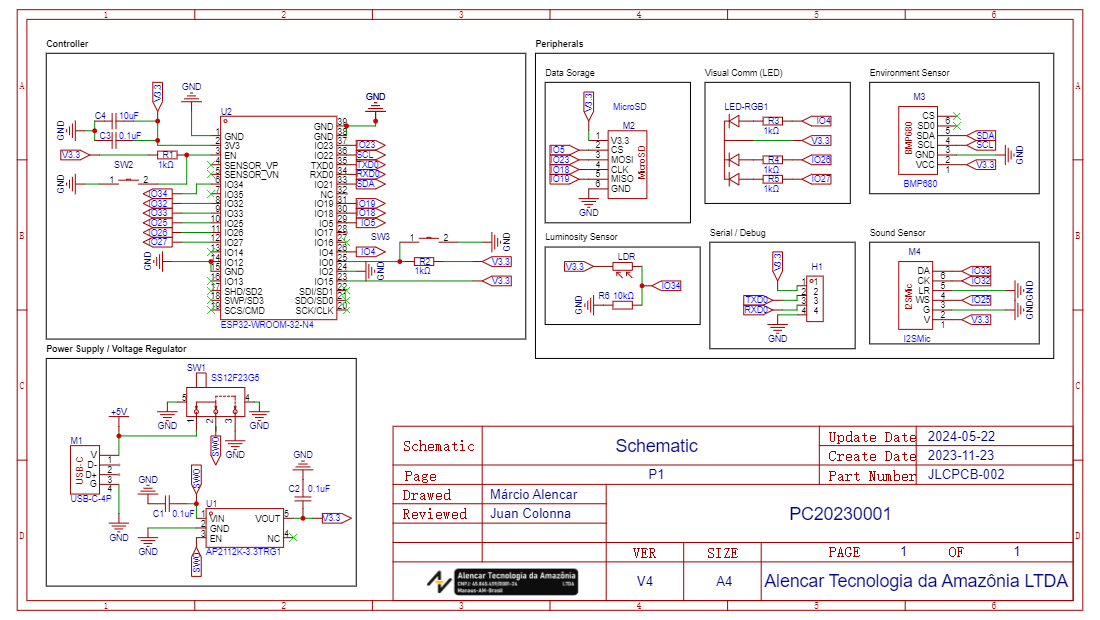
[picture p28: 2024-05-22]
board images/schematic.png

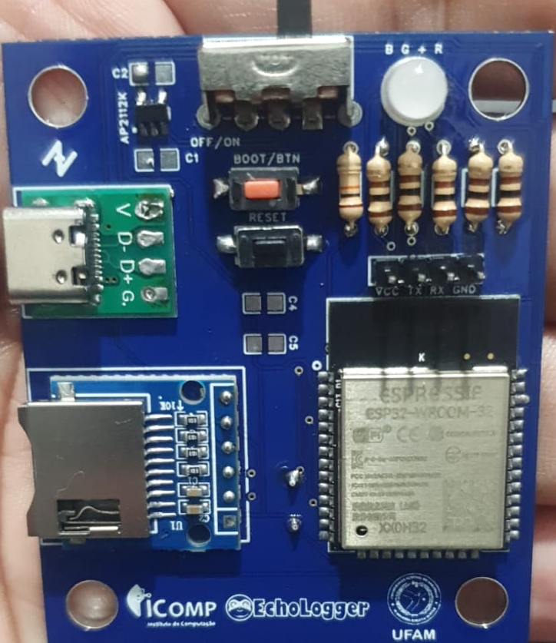
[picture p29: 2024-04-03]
board images/RealTop.jpg

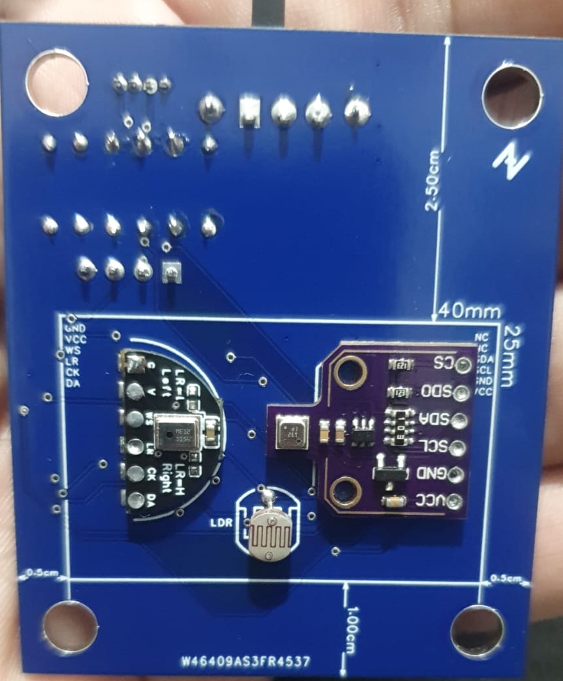
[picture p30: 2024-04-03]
board images/RealBottom.jpg

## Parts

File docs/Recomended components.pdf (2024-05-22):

### APPENDIX II – TABLE OF COMPONENTS

SCHEMATIC
DESIGNATOR | ITEM DESCRIPTION | ALIEXPRESS | REFERENCE IMAGE
1 | SW1 | SS-12F23-G5 | Link (https://pt.aliexpress.com/item/1005004402594340.html?curPageLogUid=jTmYfdcJhYBS)
2 | M1 | USB-C Module | Link (https://pt.aliexpress.com/item/1005002265536286.html?curPageLogUid=vs1gcvOQKRwY)
3 | U1 | AP2112K-3.3TRG1 | Link (https://pt.aliexpress.com/item/1005002927642789.html?curPageLogUid=JXteVTxRoX7M)
4 | SW2, SW3 | TS-1101-C-W | Link (https://pt.aliexpress.com/item/1005003512969259.html?curPageLogUid=oLNyJqIfp7PM)
5 | U2 | ESP32-WROOM-32 | Link (https://pt.aliexpress.com/item/1005006102130416.html?curPageLogUid=L7csCuRhkH8d)
6 | M2 | MicroSD Card Module | Link (https://pt.aliexpress.com/item/1005005284430059.html?curPageLogUid=ODVt3rzyeh2g)
7 | RGB LED | 5mm Common Anode RGB Led | Link (https://pt.aliexpress.com/item/32278313170.html?curPageLogUid=07iZKQ3SR1iA)
8 | M3 | BME680 | Link (https://pt.aliexpress.com/item/1005005741812414.html?curPageLogUid=DexAf6rWD42Q)
9 | M4 | I2S Microphone | Link (https://pt.aliexpress.com/item/1005004827254791.html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)
10 | LDR | 5mm LDR | Link (https://pt.aliexpress.com/item/1005005548140591.html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)
11 | R1,R2,R3,R4,R5 | Resistor 1K THP
12 | R6 | Resistor 10K THP
13 | C1,C2,C3 | Ceramic Capacitor 0.1uF SMD 0805
14 | C4 | Ceramic Capacitor 10uF SMD 0805

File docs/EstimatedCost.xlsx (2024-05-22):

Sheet: Planilha1
# | QNT | ITEM | SUBTOTAL (ITEM) | VALOR BRUTO (ITEM + FRETE) | VALOR TAXADO (60%) | LINK
1 | 10 | ESP32-WROOM-32-N8 | R$105.24 | R$126.54 | R$202.46 | ESP32 (https://pt.aliexpress.com/item/1005003331046901.html?mp=1)
2 | 10 | Módulo de Cartão MicroSD | R$11.92 | R$37.36 | R$59.78 | MicroSD (https://pt.aliexpress.com/item/1005003402512131.html?mp=1)
3 | 10 | Módulo Conector USB Tipo C - 4P | R$9.64 | R$9.64 | R$15.42 | USB-C (https://pt.aliexpress.com/item/1005005187689195.html?mp=1)
4 | 10 | Microfone I2S | R$88.66 | R$110.53 | R$176.85 | MicI2S (https://pt.aliexpress.com/item/1005006004974904.html?mp=1)
5 | 10 | Sensor BME680 | R$190.45 | R$218.38 | R$349.41 | BMP680 (https://pt.aliexpress.com/item/1005005987300470.html?mp=1)
6 | 10 | LDR 5mm | R$8.45 | R$25.89 | R$41.42 | LDR (https://pt.aliexpress.com/item/1005005699265550.html?mp=1)
7 | 10 | LED RGB 5mm - Cathodo Comum (+) | R$2.07 | R$19.38 | R$31.01 | RGB-5mm (https://pt.aliexpress.com/item/1005002724918591.html?curPageLogUid=m9rN9ekFEUOU)
8 | 30 | Resistores 1K (*100und/pct) | R$1.97 | R$24.41 | R$39.06 | Resistores (https://pt.aliexpress.com/item/1005005310500584.html?mp=1)
9 | 30 | Resistores 10K (*100und/pct) | R$1.97
10 | 20 | Chave Tactil SMD (*100und/pct) | R$4.40 | R$23.11 | R$36.98 | Botões (https://pt.aliexpress.com/item/1005003182795310.html?curPageLogUid=wgVCzClYPtFc)
11 | 10 | Regulador de Tensão LM1117-3.3v | R$3.97 | R$20.94 | R$33.50 | Regulador 1117 (https://pt.aliexpress.com/item/1005005222170322.html?mp=1)
 |  | Regulador de tensão APK2112-3.3V | R$2.88 | R$19.07 | R$30.51 | Regulador APK (https://pt.aliexpress.com/item/1005005304692948.html?mp=1)
12 | 10 | PCBWay - 60x35mm - 2F | R$24.60 | R$122.07 | R$195.30 | PCBWay
 |  |  |  | Total (10und) | R$1181.19
 |  |  |  | Estimado / Unidade | R$118.12
 |  |  |  | Cotação do Dólar | R$4.92 | 2023-09-22

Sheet: Planilha2
# | SCHEMATIC DESIGNATOR | ITEM DESCRIPTION | ALIEXPRESS | REFERENCE IMAGE
1 | SW1 | SS-12F23-G040 | Link (https://pt.aliexpress.com/item/1005004402594340.html?curPageLogUid=jTmYfdcJhYBS)
2 | M1 | USB-C Module | Link (https://pt.aliexpress.com/item/1005002265536286.html?curPageLogUid=vs1gcvOQKRwY)
3 | U1 | AP2112K-3.3TRG1 | Link (https://pt.aliexpress.com/item/1005002927642789.html?curPageLogUid=JXteVTxRoX7M)
4 | SW2, SW3 | TS-1101-C-W | Link (https://pt.aliexpress.com/item/1005003512969259.html?curPageLogUid=oLNyJqIfp7PM)
5 | U2 | ESP32-WROOM-32 | Link (https://pt.aliexpress.com/item/1005006102130416.html?curPageLogUid=L7csCuRhkH8d)
6 | M2 | MicroSD Card Module | Link (https://pt.aliexpress.com/item/1005005284430059.html?curPageLogUid=ODVt3rzyeh2g)
7 | RGB LED | 5mm Common Anode RGB Led | Link (https://pt.aliexpress.com/item/32278313170.html?curPageLogUid=07iZKQ3SR1iA)
8 | M3 | BME680 | Link (https://pt.aliexpress.com/item/32898175027.html?scm_id=1007.40050.362094.0&scm-url=1007.40050.362094.0)
9 | M4 | I2S Microphone | Link (https://pt.aliexpress.com/item/1005006004974904.html?curPageLogUid=QgCs6hMEwJXJ)
10 | R6 | 5mm LDR | Link (https://pt.aliexpress.com/item/1005005391213072.html?curPageLogUid=Zh6vjx9bFxR8)
11 | R1,R2,R3,R4,R5 | Resistor 1K THP
12 | R7 | Resistor 10K THP
13 | C1,C2 | Ceramic Capacitor 0.1uF SMD 0805
14 | C3 | Ceramic Capacitor 10uF SMD 0805

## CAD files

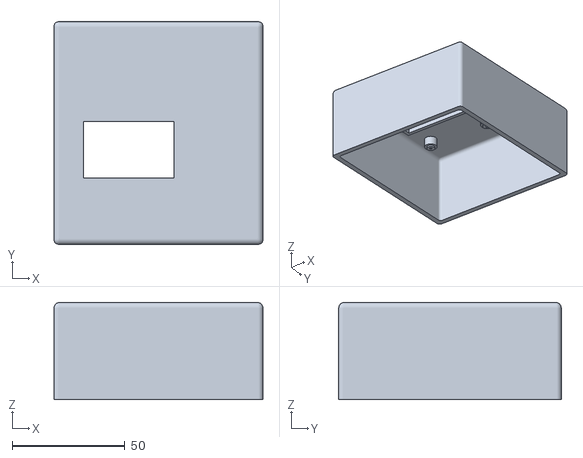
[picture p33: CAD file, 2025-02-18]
case/2_Tapa_Echologger.stl
92.5 x 98.5 x 43.0

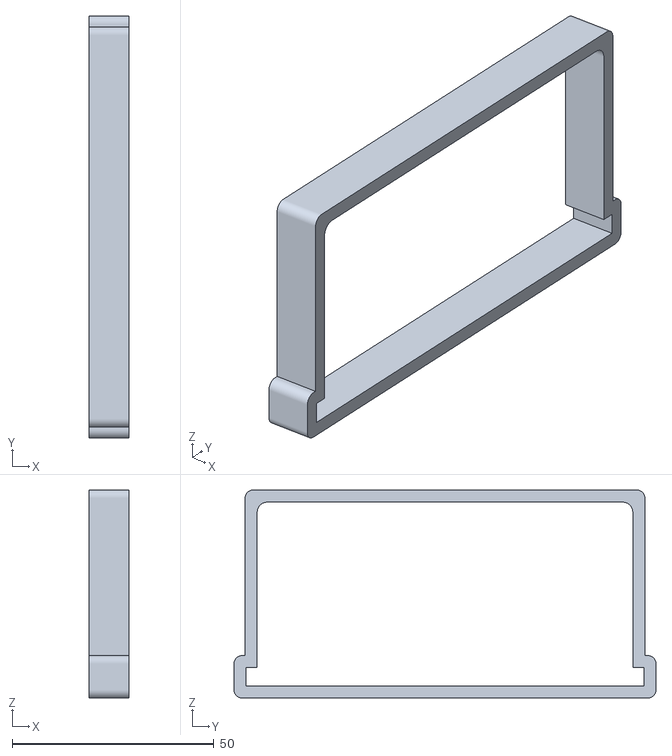
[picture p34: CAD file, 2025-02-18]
case/4_Traba_Echologger.stl
10.0 x 104.5 x 51.5

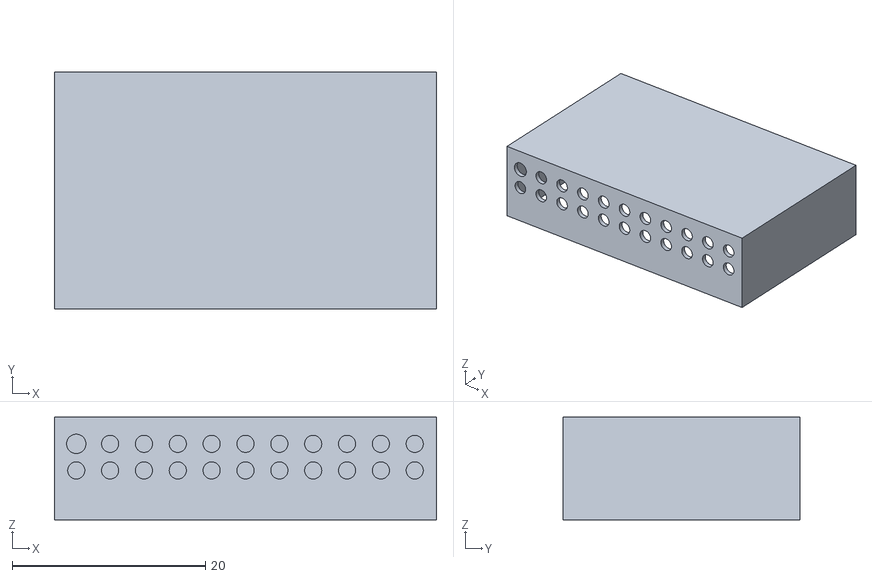
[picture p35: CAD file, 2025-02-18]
case/3_ventana_Echologger.stl
39.5 x 24.5 x 10.6

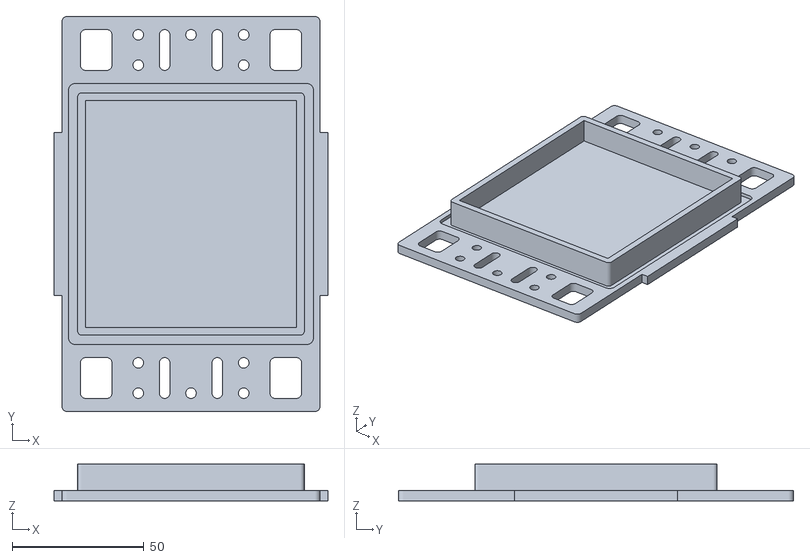
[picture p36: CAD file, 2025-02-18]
case/1_base_Echologger.stl
104.0 x 150.0 x 14.0

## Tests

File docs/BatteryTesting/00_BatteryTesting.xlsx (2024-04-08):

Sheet: WiFi+Sensors
Cenário de Teste |  |  |  | Dados Thingspeak
EchoLogger alimentado por uma bateria 18650, totalmente carregada (4.2V) conectada a um conversor DC-DC (3.7 para 5V). Envio de dados a cada 30s via WiFi (2.4 GHz) de todos os sensores ambientais (exceto áudio), Sem deepsleep e sem gravação no cartão SD |  |  |  | timestamp | temperatura | umidade | pressao | qualidade | luminosidade
 |  |  |  | 2024-03-02T14:24:54-04:00 | 32.4 | 68.76 | 1004.67 | 6.8 | 0
 |  |  |  | 2024-03-02T14:25:24-04:00 | 32.46 | 68.15 | 1004.67 | 0.37 | 0
 |  |  |  | 2024-03-02T14:25:54-04:00 | 32.54 | 67.67 | 1004.65 | 0.59 | 0
 |  |  |  | 2024-03-02T14:26:24-04:00 | 32.64 | 67.22 | 1004.64 | 0.87 | 0
Resultados |  |  |  | 2024-03-02T14:26:54-04:00 | 32.74 | 66.95 | 1004.63 | 1.08 | 0
 | Hora | Tensão Bateria(V) | Registros | 2024-03-02T14:27:24-04:00 | 32.83 | 66.69 | 1004.62 | 1.29 | 0
Início | 2024-03-02 14:24 | 4.2 | 0 | 2024-03-02T14:27:54-04:00 | 32.92 | 66.51 | 1004.6 | 1.54 | 0
Fim | 2024-03-03 02:43 | 3 | 1479 | 2024-03-02T14:28:24-04:00 | 33 | 66.28 | 1004.58 | 1.77 | 0
TOTAL | 12.32 | 1.2 | 1479 | 2024-03-02T14:28:54-04:00 | 33.08 | 66.29 | 1004.54 | 1.97 | 100
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

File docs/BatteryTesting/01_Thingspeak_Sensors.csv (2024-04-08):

timestamp | temperatura | umidade | pressao | qualidade | luminosidade
2024-03-02T14:24:54-04:00 | 32,4 | 68,76 | 1004,67 | 6,8 | 0
2024-03-02T14:25:24-04:00 | 32,46 | 68,15 | 1004,67 | 0,37 | 0
2024-03-02T14:25:54-04:00 | 32,54 | 67,67 | 1004,65 | 0,59 | 0
2024-03-02T14:26:24-04:00 | 32,64 | 67,22 | 1004,64 | 0,87 | 0
2024-03-02T14:26:54-04:00 | 32,74 | 66,95 | 1004,63 | 1,08 | 0
2024-03-02T14:27:24-04:00 | 32,83 | 66,69 | 1004,62 | 1,29 | 0
2024-03-02T14:27:54-04:00 | 32,92 | 66,51 | 1004,6 | 1,54 | 0
2024-03-02T14:28:24-04:00 | 33 | 66,28 | 1004,58 | 1,77 | 0
2024-03-02T14:28:54-04:00 | 33,08 | 66,29 | 1004,54 | 1,97 | 100
2024-03-02T14:29:24-04:00 | 33,14 | 65,07 | 1004,5 | 2,19 | 100
2024-03-02T14:29:54-04:00 | 33,18 | 64,94 | 1004,47 | 2,42 | 100
2024-03-02T14:30:24-04:00 | 33,19 | 65,03 | 1004,43 | 2,65 | 100
2024-03-02T14:30:54-04:00 | 33,19 | 65,06 | 1004,42 | 3,08 | 100
2024-03-02T14:31:24-04:00 | 33,2 | 64,89 | 1004,4 | 3,34 | 100
2024-03-02T14:31:54-04:00 | 33,2 | 64,82 | 1004,38 | 3,63 | 100
2024-03-02T14:32:24-04:00 | 33,19 | 65,03 | 1004,37 | 3,95 | 100
2024-03-02T14:32:54-04:00 | 33,15 | 65,17 | 1004,35 | 4,3 | 100
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

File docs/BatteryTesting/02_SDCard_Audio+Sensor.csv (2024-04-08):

timestamp | temperatura(C) | umidade(%) | pressao(Pa) | gas(ohms) | luminisidade(%)
2024-03-14 22:15:03 | 34,44 | 63,72 | 1004,42 | 16,76 | 0
2024-03-14 22:25:07 | 33,94 | 64,29 | 1004,4 | 24,38 | 17,27
2024-03-14 22:35:10 | 33,42 | 66,31 | 1004,28 | 29,6 | 0
2024-03-14 22:45:14 | 33,82 | 64,84 | 1004,26 | 32,56 | 0
2024-03-14 22:55:18 | 33,91 | 64,57 | 1004,08 | 34,44 | 0
2024-03-14 23:05:21 | 33,33 | 66,69 | 1004 | 36,73 | 0
2024-03-14 23:15:25 | 33,66 | 65,31 | 1004 | 37,93 | 0
2024-03-14 23:25:29 | 33,2 | 67,14 | 1004,14 | 39,35 | 0
2024-03-14 23:35:32 | 32,94 | 67,73 | 1004,1 | 40,76 | 0
2024-03-14 23:45:36 | 33,51 | 65,62 | 1004 | 40,9 | 0
2024-03-14 23:55:40 | 33,05 | 67,6 | 1004,01 | 41,76 | 0
2024-03-15 00:05:44 | 32,74 | 68,29 | 1003,86 | 43,03 | 0
2024-03-15 00:15:47 | 32,67 | 68,29 | 1003,7 | 43,7 | 0
2024-03-15 00:25:51 | 33,25 | 65,94 | 1003,58 | 43,58 | 0
2024-03-15 00:35:55 | 32,84 | 67,59 | 1003,38 | 44,27 | 0
2024-03-15 00:45:58 | 32,64 | 68,02 | 1003,31 | 45,29 | 0
2024-03-15 00:56:02 | 33,11 | 66,16001 | 1003,3 | 44,88 | 0
2024-03-15 01:06:06 | 32,71 | 67,78 | 1003,2 | 45,77 | 0
2024-03-15 01:16:10 | 32,54 | 68,41001 | 1003,05 | 46,41 | 0
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

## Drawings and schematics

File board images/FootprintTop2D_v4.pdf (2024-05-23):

## BOOT/BTN

C2

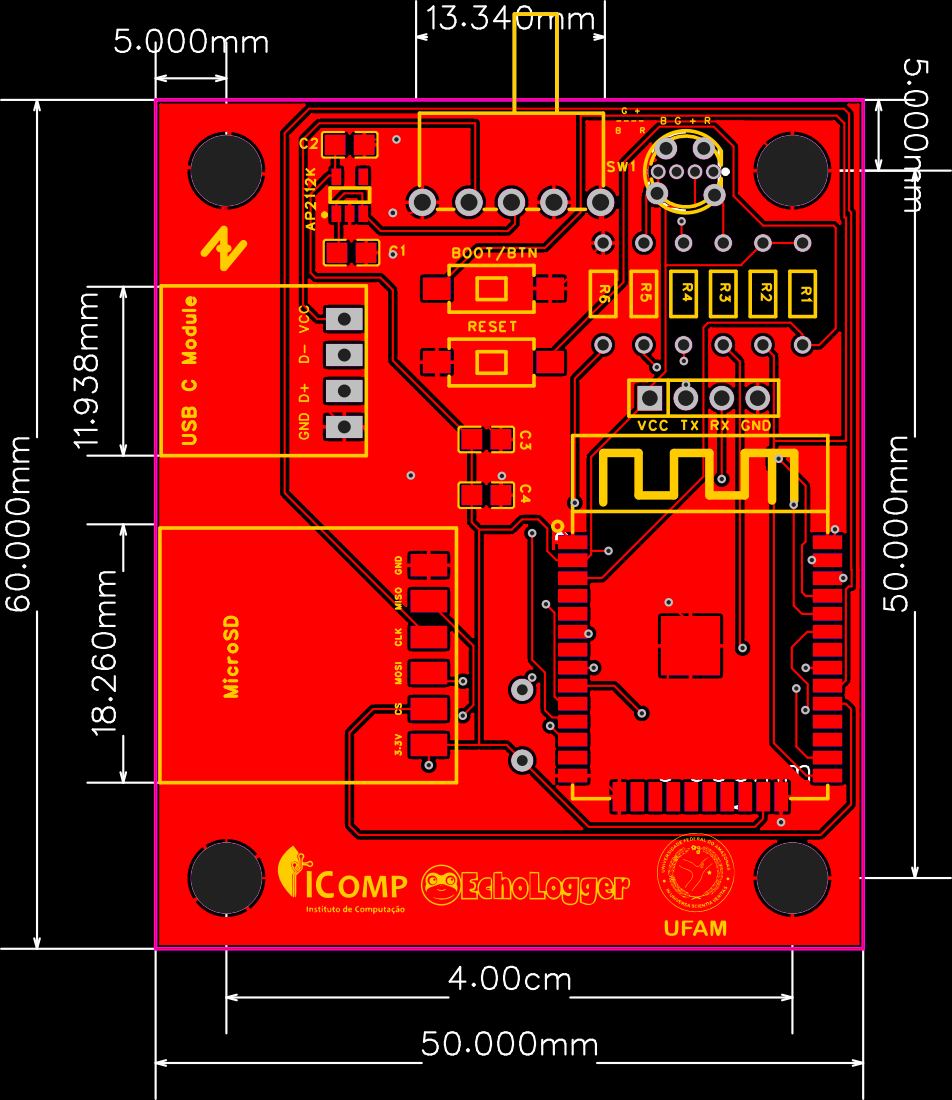
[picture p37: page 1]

3.3V CS MOSI CLK MISO GND

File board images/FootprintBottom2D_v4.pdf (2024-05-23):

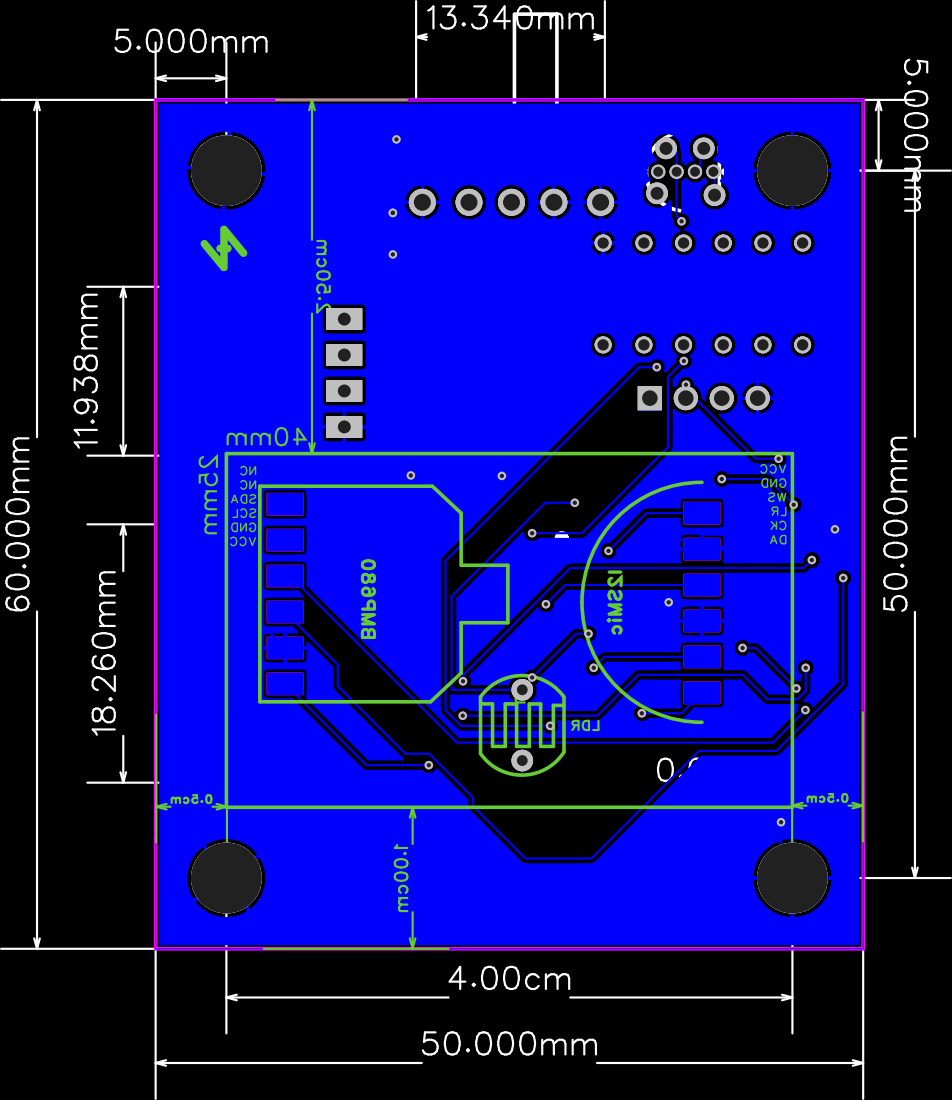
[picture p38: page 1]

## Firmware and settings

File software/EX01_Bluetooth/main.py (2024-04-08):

import random
import struct
import os
import bluetooth
import time
from micropython import const
from machine import Pin, Timer, SoftI2C, ADC, Timer, RTC, SDCard
from ble_advertising import advertising_payload
from bme680 import *
import i2smic
import RGBLib


#RGB LED
LED = RGBLib.Controller(4,26,27)

# RTC FUNCTION
CLOCK = RTC()

# BLUETOOTH LOW ENERGY ADVERTISERMENTS
_UART_UUID =  bluetooth.UUID(0x181A)
_UUIDBASE="{}-B5A3-F393-E0A9-E50E24DCCA9E"  
_UART_RX = (bluetooth.UUID(_UUIDBASE.format("6E400002")),0x0008 | 0x0004,) # receive from app
_UART_TX = (bluetooth.UUID(_UUIDBASE.format("6E400003")),0x0002 | 0x0010,) # send to app
_UART_PRES = ( bluetooth.UUID(0x2A6D),0x0002 | 0x0010,) # Pressure hPA
_UART_TEMP = ( bluetooth.UUID(0x2A6E),0x0002 | 0x0010,) # Temperature ºC
_UART_HUMI = ( bluetooth.UUID(0x2A6F),0x0002 | 0x0010,) # Humidity %
_UART_AQUA = ( bluetooth.UUID(0x2AF9),0x0002 | 0x0010,) # Generic Level 
_UART_LUMI = ( bluetooth.UUID(0x2AFB),0x0002 | 0x0010,) # Illuminance %
_UART_TIME = ( bluetooth.UUID(0x2B90),0x0002 | 0x0010,) # Current device time sec from 2000/01/01 00:00:00
_UART_SDCARD = ( bluetooth.UUID(0x2B04),0x0002 | 0x0010,) # Percentage (%)
_ADV_APPEARANCE_MULTISENSOR = const(1366) # Multisensor

_UART_SERVICE = (_UART_UUID,(_UART_TX, _UART_RX, _UART_TEMP, _UART_HUMI, _UART_PRES, _UART_AQUA, _UART_LUMI, _UART_TIME, _UART_SDCARD),)

# LDR SENSOR (ANALOGIC INTERFACE)
adc = ADC(Pin(34))
_MAXL = 65535

# BMP680 SENSOR (I2C INTERFACE)
i2c = SoftI2C(scl=Pin(22), sda=Pin(21))
bme = BME680_I2C(i2c=i2c)

#i2S MICROPHONE
MIC = i2smic.Controller()

#SDCard Controller
_SD=None
try:
     _SD = SDCard(slot=2)
     os.mount(_SD, "/sd") 
except:_SD=None


#BLUETOOT TIMERS
BLESerial=""
BLEPeriod=5000
IMUTimer=Timer(2)
random.seed(123)

#--------------------------------- FUNCTIONS ----------------------------------------#
class BLEPeripheral:
     #declare status, handles and operation mode
     def __init__(self, ble, name="EchoLogger"):
          self._ble = ble
          self._ble.active(True)
          self._ble.irq(self._irq)
          ((self._handle_tx, self._handle_rx, self._handle_temp, self._handle_humi, self._handle_pres, self._handle_aqua, self._handle_lumi,self._handle_time, self._handle_sdcard),) = self._ble.gatts_register_services((_UART_SERVICE,))
          self._connections = set()
          self._write_callback = None
          self._payload = advertising_payload(name=name, services=[_UART_UUID], appearance=_ADV_APPEARANCE_MULTISENSOR,)
          self._advertise()

     #Handler ble interruptions
     def _irq(self, event, data):
          if event == 1:
               conn_handle, _, _ = data
               print("Connected", conn_handle)
               self._connections.add(conn_handle)
               LED.set('green')
               IMUTimer.init(period=BLEPeriod, mode=Timer.PERIODIC, callback=readSensor)
          elif event == 2:
               conn_handle, _, _ = data
               print("Disconnected", conn_handle)
               LED.set('white')
               IMUTimer.deinit()
               self._connections.remove(conn_handle)
               self._advertise()
          elif event == 3:
               conn_handle, value_handle = data
               value = self._ble.gatts_read(value_handle)
               if value_handle == self._handle_rx and self._write_callback:
                    self._write_callback(value)

     #Send message
     def send(self, data):
          for conn_handle in self._connections:
               self._ble.gatts_notify(conn_handle, self._handle_tx, data)
     
     #Update advertisers
     def update_vals(self, data):
          
          self._ble.gatts_write(self._handle_temp, bytearray(struct.pack("f",data["temp"])),True)
          self._ble.gatts_write(self._handle_humi, bytearray(struct.pack("f",data["humi"])),True)
          self._ble.gatts_write(self._handle_pres, bytearray(struct.pack("f",data["pres"])),True)
          self._ble.gatts_write(self._handle_lumi, bytearray(struct.pack("f",data["lumi"])),True)
          self._ble.gatts_write(self._handle_aqua, bytearray(struct.pack("f",data["aqua"])),True)
          self._ble.gatts_write(self._handle_time, bytearray(struct.pack("f",data["time"])),True)
          self._ble.gatts_write(self._handle_sdcard, bytearray(struct.pack("f",data["sdcard"])),True)

          #Update values notifying clients
          #for conn_handle in self._connections:     
               #self._ble.gatts_notify(conn_handle, self._handle_temp, bytearray(struct.pack("f",data["temp"])))
               #self._ble.gatts_notify(conn_handle, self._handle_humi, bytearray(struct.pack("f",data["humi"])))
               #self._ble.gatts_notify(conn_handle, self._handle_pres, bytearray(struct.pack("f",data["pres"])))
               #self._ble.gatts_notify(conn_handle, self._handle_lumi, bytearray(struct.pack("f",data["lumi"])))
               #self._ble.gatts_notify(conn_handle, self._handle_aqua, bytearray(struct.pack("f",data["aqua"])))
               #self._ble.gatts_notify(conn_handle, self._handle_time, bytearray(struct.pack("f",data["time"])))
               #self._ble.gatts_notify(conn_handle, self._handle_sdcard, bytearray(struct.pack("f",data["sdcard"])))
               
     #check connections
     def is_connected(self):
          return len(self._connections) > 0

     #start advertiserment
     def _advertise(self, interval_us=500000):
          print("Advertising")
          self._ble.gap_advertise(interval_us, adv_data=self._payload)

     #receive data callback
     def on_write(self, callback):
          self._write_callback = callback   

#read all information you want to advertise
def readSensor(t):
     global BLESerial, bme
     pkg = {}
     pkg["time"]=time.time() # s from 2000
     pkg["temp"]=round(bme.temperature, 2) # ºC
     pkg["humi"]=round(bme.humidity, 2) # %
     pkg["pres"]=round(bme.pressure, 2) #avg sea level: 1013,25 
     pkg["lumi"]=int(round((adc.read_u16() / _MAXL * 100),2))
     pkg["aqua"]=round(bme.gas/1000, 2) #values ranges in https://cdn-shop.adafruit.com/product-files/3660/BME680.pdf
     _,_,x,y,_,_,_,_,_,_=os.statvfs('/sd/'); 
     pkg["sdcard"]=round(100*(y/x),2)
     print(pkg)
     #send data to bluetooth
     BLESerial.update_vals(pkg)

#Gets the last record on the SDCard and return the new filename
def new_file():
     FCount = 0
     FPath="/sd/record_{}.wav"
     try: 
          while os.stat(FPath.format(FCount)):
               FCount+=1
     except:pass
     return FPath.format(FCount)

#blueototh callback function to handle incoming data
def on_rx(v):
     global BLESerial
     print("RX", v)
     if v.startswith(b"time:"):    #time:YYYYMMDDhhmmss
          #UNIX_OFFSET=946684800
          tstamp = v.decode('utf-8').split(":")[1]
          ano = int(tstamp[:4],10)
          mes = int(tstamp[4:6],10)
          dia = int(tstamp[6:8],10)
          hora = int(tstamp[8:10],10)
          minuto = int(tstamp[10:12],10)
          segundo = int(tstamp[12:14],10)
          CLOCK.datetime((ano,mes,dia,0,hora,minuto,segundo,0))
          BLESerial.send("status:clock_ok")
     elif v.startswith(b"gps:"): #gps:-0123.456;987.5212
          coord = v.decode('utf-8').split(":")[1]
          lat,lon = coord.split(';')
          gps={"lat":lat,"lon":lon}
          print(gps)
          BLESerial.send("status:gps_ok")
     elif v.startswith("led"): #led:color
          label = v.decode('utf-8').split(":")[1]
          LED.set(label)
          BLESerial.send("status:led_ok")
     elif v.startswith("rgb"): #led:r,g,b
          r,g,b,h = v.decode('utf-8').split(":")[1].split(',')
          LED.man(int(r,10)*4,int(g,10)*4,int(b,10)*4)          
          BLESerial.send("status:rgb_ok")
     elif v.startswith("mic:record"):
          LED.set('orange')
          filepath=new_file()
          BLESerial.send("status:{}".format(filepath))
          MIC.record(filepath)
     elif v.startswith("mic:stop"):
          LED.set('green')
          MIC.stop()
          BLESerial.send("status:stoped") 
     else:
          BLESerial.send("status:fail")    

def loadBluetooth():
     try: 
          global BLESerial, LED, SD
          ble = bluetooth.BLE()
          BLESerial = BLEPeripheral(ble)
          BLESerial.on_write(on_rx)
          print("Bluetooth Loaded...")
     except Exception as e:
          print(e)
          pass
#--------------------------------- BOOT ----------------------------------------#

LED.boot()
loadBluetooth() 
#IMUTimer.init(period=BLEPeriod, mode=Timer.PERIODIC, callback=readSensor)

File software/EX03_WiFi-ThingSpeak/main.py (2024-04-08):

import network
import os
import time
from machine import Pin, Timer, SoftI2C, ADC, Timer, RTC, Timer
import bme680
import RGBLib
import mrequests
import ntptime

#Thingspeak
_APIKEY = "NZEKR612C60Y0PL1" #<<--CHANGE THIS
_URL='https://api.thingspeak.com/update?api_key={}&field1={}&field2={}&field3={}&field4={}&field5={}'

#Wifi Credentials
_SSID="WLANCutia" #<<--CHANGE THIS
_PWD ="!1a2b_3c4d!E" #<<--CHANGE THIS


#UPDATE TIMER
UpdatePeriod=5000
UPDTimer=Timer(2)

#RGB LED
LED = RGBLib.Controller(4,26,27)

# LDR SENSOR (ANALOGIC INTERFACE)
adc = ADC(Pin(34), atten=ADC.ATTN_6DB) #10kOhm - 3.3v

_MAXL = 65535

# BMP680 SENSOR (I2C INTERFACE)
i2c = SoftI2C(scl=Pin(22), sda=Pin(21))
bme = bme680.BME680_I2C(i2c=i2c)

_NET = None

def readSensor():
     global bme, adc, _MAXL
     pkg = {}
     pkg["temp"]=round(bme.temperature, 2) # ºC
     pkg["humi"]=round(bme.humidity, 2) # %
     pkg["pres"]=round(bme.pressure, 2) #avg sea level: 1013,25 
     pkg["lumi"]=int(round((adc.read_u16() / _MAXL * 100),2))
     pkg["aqua"]=round(bme.gas/1000, 2) #values ranges in https://cdn-shop.adafruit.com/product-files/3660/BME680.pdf
     return pkg

def send_package(FilledURL):
    try: 
        print(FilledURL)
        response = mrequests.request('GET',FilledURL)
        print("send_package: got", response.status_code)#, response.content, "on sending", PKG)
        print("send_package: content", response.content)
        if response.status_code == 200: return True
        return False
    except Exception as e: 
        raise Exception("(send_pkg): error on {}".format(str(e)))


def load_wifi(ssid, pwd):
     global _NET
     _NET = network.WLAN(network.STA_IF)
     _NET.active(True)
     time.sleep(1)
     _NET.config(dhcp_hostname="EchoLogger")
     time.sleep(1)
     _NET.connect(ssid,pwd)
     for _ in range(10):
          LED.set('cyan')
          if _NET.isconnected(): 
                LED.set('green')
                return True
          LED.set('red')
          time.sleep(3)
     return False
 

def uploadValues(t):
     global _URL, _APIKEY
     #THINGSPEAK - Public View @ https://thingspeak.com/channels/2390384#
     #Fields: 1-Temperature, 2-Humidity, 3-AirPressure, 4-AirQuality, 5-LightIntensity
     LED.set('orange')
     
     data = readSensor()
     #Fields: 1-Temperature, 2-Humidity, 3-AirPressure, 4-AirQuality, 5-LightIntensity     
     if send_package(_URL.format(_APIKEY, data['temp'],data["humi"],data["pres"],data["aqua"],data["lumi"])):
          LED.set('green')
     else:
          LED.set('red')
     time.sleep(3)
     LED.set('cyan')

#BUTTON HANDLER
def btn_callback(t):
     if BTN.value()==0:
          print("Emergency break!")   
          UPDTimer.deinit()
     time.sleep(2)
     print("Terminal Unlocked")
     
BTN = Pin(0, Pin.IN)       
BTN.irq(trigger=Pin.IRQ_FALLING, handler=btn_callback)

     
#--------------------------------- BOOT ----------------------------------------#

LED.boot()

if load_wifi(_SSID,_PWD):
     ntptime.settime()
     print("current time {}".format(str(time.localtime())))
     UPDTimer.init(period=30000, mode=Timer.PERIODIC, callback=uploadValues)

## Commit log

2024-04-03 Create Schematic
2024-04-08 Files to fabricate the board
2024-04-08 battery saver example
2024-05-22 new datasheet version v3
    [EstimatedCost.xlsx]
2024-05-22 new board corrections
2024-05-22 schematic update
2025-02-11 Board 3D view
2025-02-11 PCB 3D view
2025-02-11 Update with EasyEDA Pro
    Changed dimension units to millimeters
2025-02-18 STL files for case 3D printing
    [1_base_Echologger.stl, 2_Tapa_Echologger.stl, 3_ventana_Echologger.stl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]
